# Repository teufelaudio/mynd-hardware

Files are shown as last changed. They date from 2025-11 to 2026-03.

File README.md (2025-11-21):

# Teufel MYND Hardware Repository
This repository contains all hardware related files including 3d models, schematics and pcb-layout files in various formats.

# Project structure
## `CAD/`
Contains 3d construction files in Rhino, STEP and STL formats. 
For every format, individual parts are available as direct download or a 'complete' package is avialable containing the entire model.
Due to size, the complete model in STL format is compressed into 'complete.zip'.

## `PCB_Schematics/`
### `./Altium`
Contains Altium Designer PCB and schematic files for all PCBs.
### `./KiCad`
Contains KiCad PCB and schematic files for all PCBs. Please note: These files were converted from the Altium working files for convenience and may still contain some  conversion errors.
### `./PDF`
Contains all schematic and assembly drawings exported to PDF from Altium files.

## Don't Yet Own a MYND Speaker!?
Purchase one [here](https://teufel.de/mynd)!

# Clone
```shell
git clone git@github.com:teufelaudio/mynd-hardware.git
```

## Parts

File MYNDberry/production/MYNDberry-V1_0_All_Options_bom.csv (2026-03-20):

Designator | Footprint | Quantity | Value | LCSC Part #
C1 | 0603 | 1 | 1µF/12V | C15849
C2 | 0603 | 1 | 2.2µF/16V | C23630
C3 | 0603 | 1 | 100nF/50V | C14663
CN1 | CONN-SMD_4P-P1.00_SHOU-HAN_1.0-4P-WT | 1 | 1.0-4P WT | C2906270
H1 | HDR-SMD_24P-P2.54-V-F-R2-C12-S7.4 | 1 | MYND_Main_PCB | C3294470
H2 | 2x40_2.54mm_Female_SMT_Vertical | 1 | RPi | C5345531
H3 | HDR-SMD_3P-P2.54-H-M_KH-2.54PH-1X3P-L13.5-WT | 1 | HX_PZ2.54-1X3P_WT | C46061676
Q1 | SOT-23-3_L2.9-W1.3-P1.90-LS2.4-BR | 1 | AO3400A | C20917
Q2 | SOT-23_L2.9-W1.3-P1.90-LS2.4-BR | 1 | AO3401A | C15127
R1, R3, R4, R5, R6, R7 | 0603 | 6 | 0R | C21189
R12, R9 | 0603 | 2 | 100k | C25803
R8 | 0603 | 1 | 470 | C23179
U1 | SOT-23-5_L3.0-W1.7-P0.95-LS2.8-BR | 1 | TPS70933DBVR | C89347
U2 | SOP-8_L4.9-W3.9-P1.27-LS6.0-BL | 1 | CH340N | C2977777

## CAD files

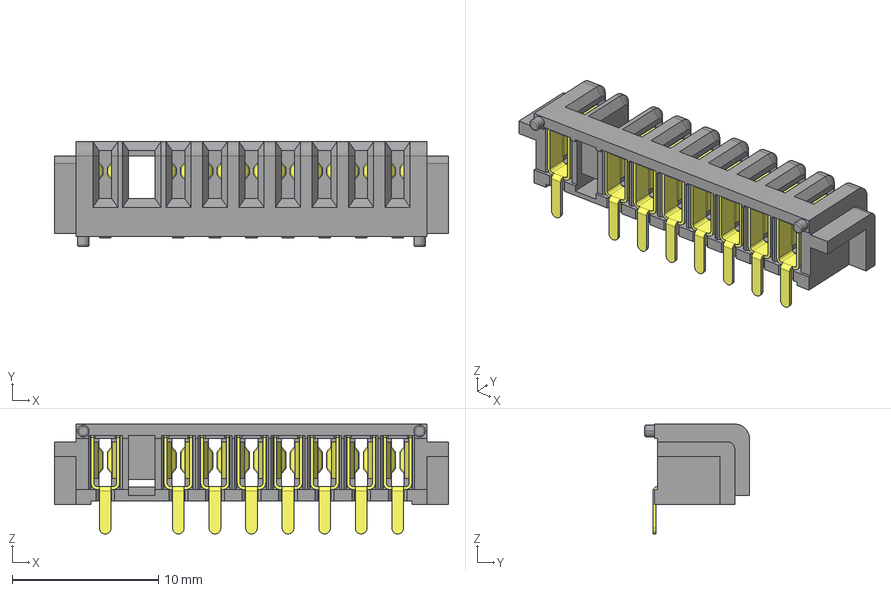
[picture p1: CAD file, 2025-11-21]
PCB_Schematics/KiCad/Conn_Amp/ALTIUM_EMBEDDED_MODELS/tsb0-0128d-00xxa_asm__sw0001.stp
26.9 x 7.18 x 7.52 mm

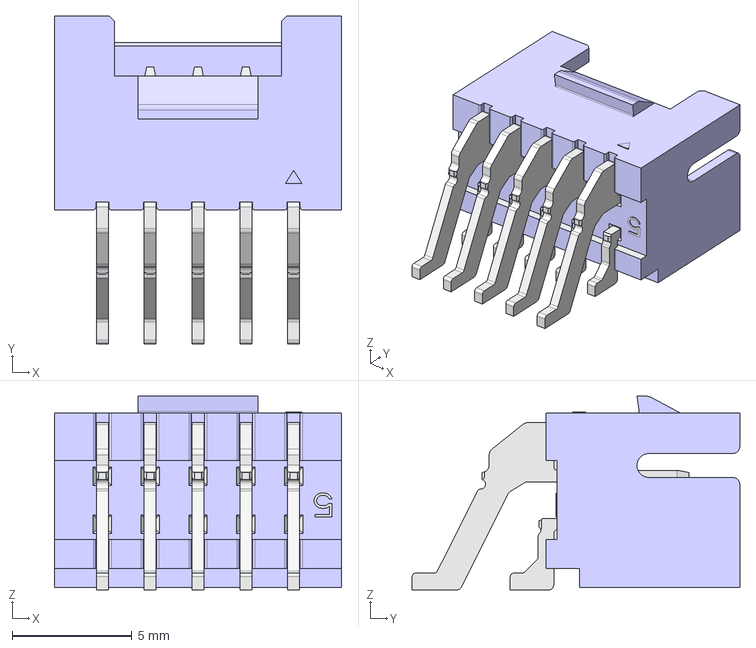
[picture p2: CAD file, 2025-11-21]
PCB_Schematics/KiCad/Jack_USB/ALTIUM_EMBEDDED_MODELS/PHB-ROW-ST-SMT-2-5P_ASM.step
12.0 x 13.7 x 8.10 mm

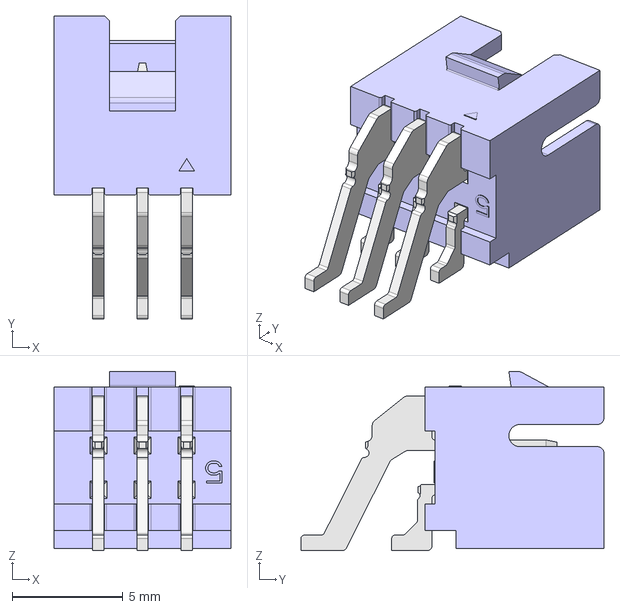
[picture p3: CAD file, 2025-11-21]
PCB_Schematics/KiCad/Jack_Line_In/ALTIUM_EMBEDDED_MODELS/phb-row-st-smt-2-3p_asm.stp
8.00 x 13.7 x 8.10 mm

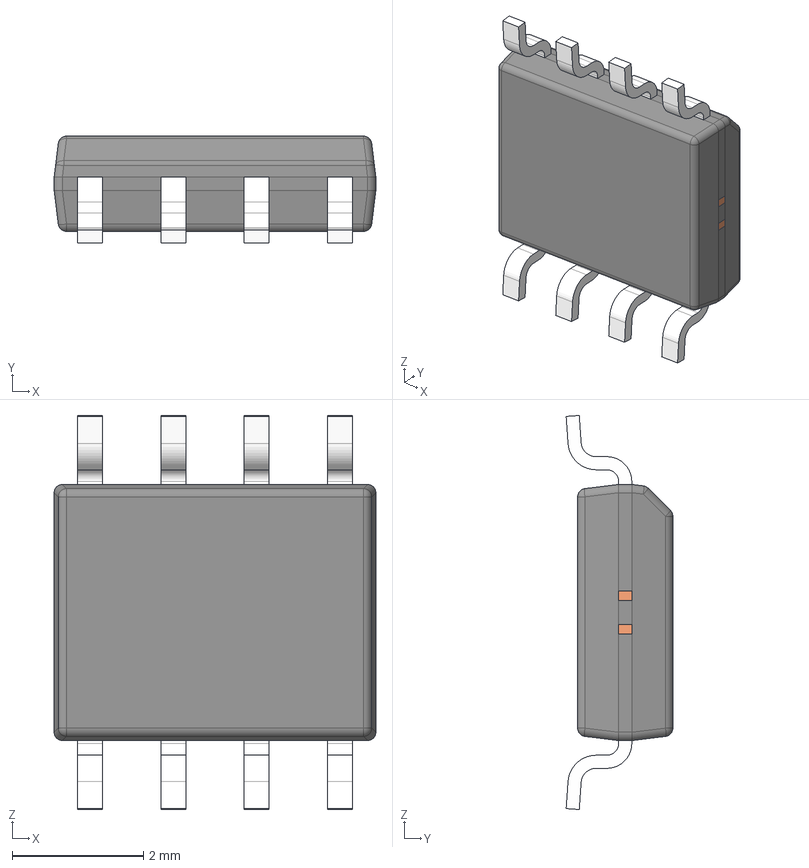
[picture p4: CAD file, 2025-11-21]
PCB_Schematics/Altium/Main/ALTIUM_EMBEDDED_MODELS/D0008A.stp
4.90 x 1.62 x 6.00 mm
BODY_M08A_35
LEAD_M08A_57 x 8
MANIFOLD_SOLID_BREP_2784
MANIFOLD_SOLID_BREP_2935
MANIFOLD_SOLID_BREP_3086
MANIFOLD_SOLID_BREP_3237

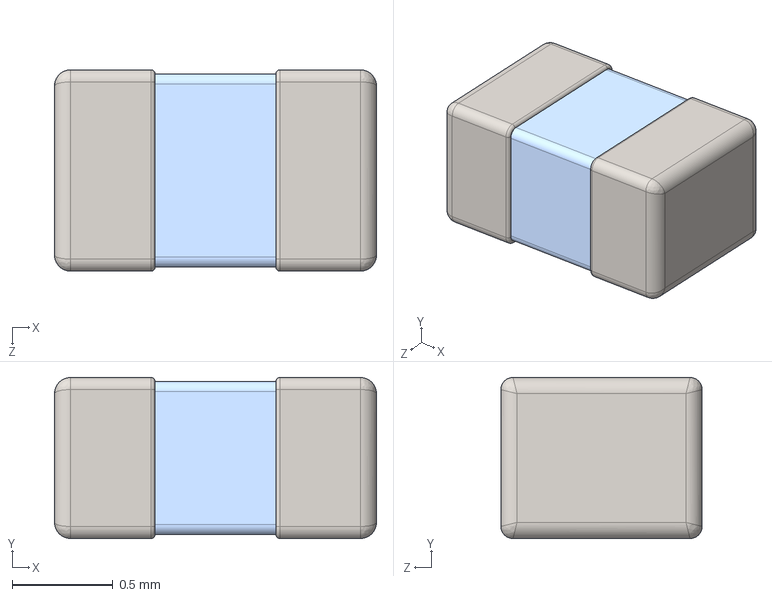
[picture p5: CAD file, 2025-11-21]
PCB_Schematics/KiCad/Amp/ALTIUM_EMBEDDED_MODELS/User Library-INDC1608X___.step
1.60 x 0.8 x 1.00 mm

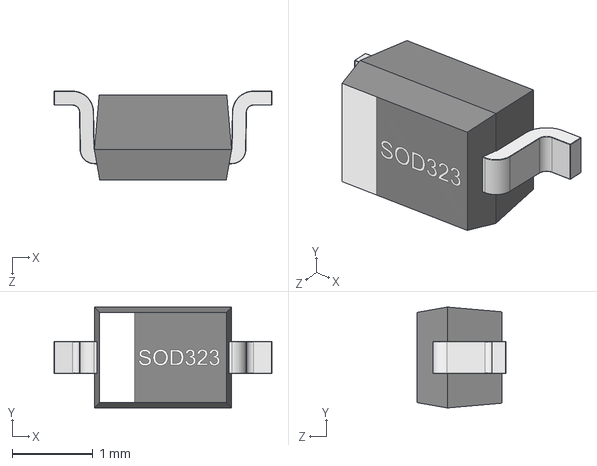
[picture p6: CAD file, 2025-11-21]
PCB_Schematics/KiCad/Bluetooth/ALTIUM_EMBEDDED_MODELS/User Library-SOD2513X11.STEP
2.70 x 1.25 x 1.10 mm

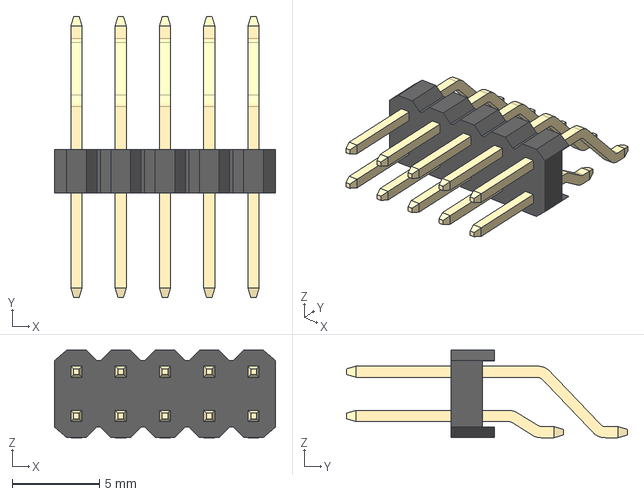
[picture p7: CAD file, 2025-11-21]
PCB_Schematics/KiCad/Conn_Amp/ALTIUM_EMBEDDED_MODELS/pin_header_a-sl254-da-g10mp1.stp
12.7 x 16.1 x 5.02 mm

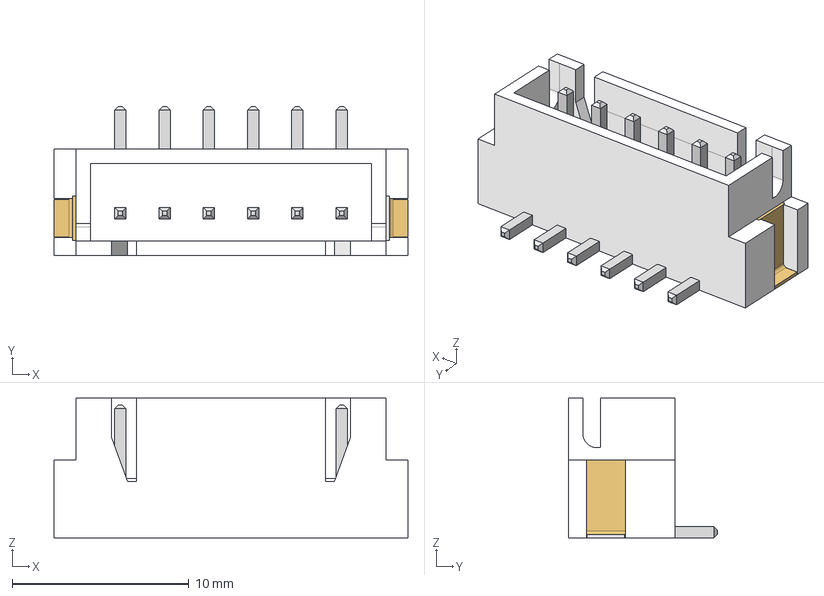
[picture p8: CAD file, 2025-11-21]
PCB_Schematics/KiCad/Conn_Baffle/ALTIUM_EMBEDDED_MODELS/A2501_6P.step
20.0 x 8.40 x 7.90 mm
Pin004
Pin005
Pin006
Pin007
Pin008
Pin009
FPin001
FPin002
FPin002_(Mirror_#1)

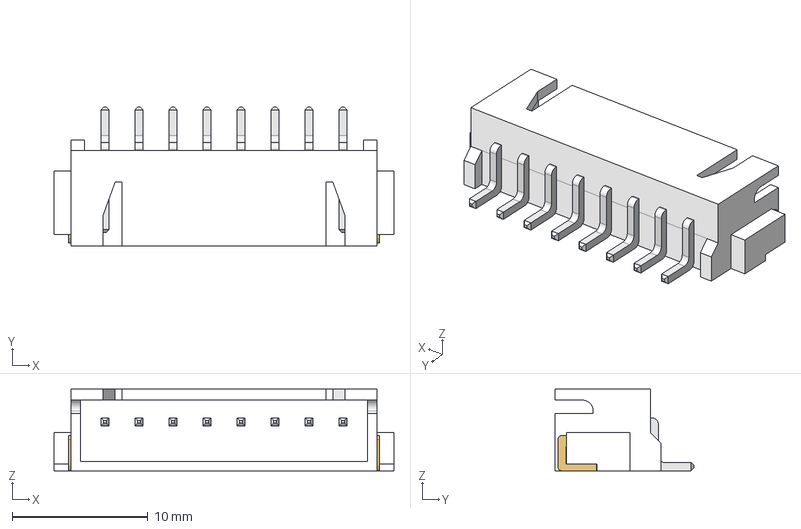
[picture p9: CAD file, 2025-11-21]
PCB_Schematics/KiCad/Conn_Bat/ALTIUM_EMBEDDED_MODELS/A2501W_8P.step
25.0 x 10.2 x 6.00 mm
FPin001
FPin002
FPin002_(Mirror_#1)
PIN001
PIN002
PIN003
PIN004
PIN005
PIN006
PIN007
PIN008

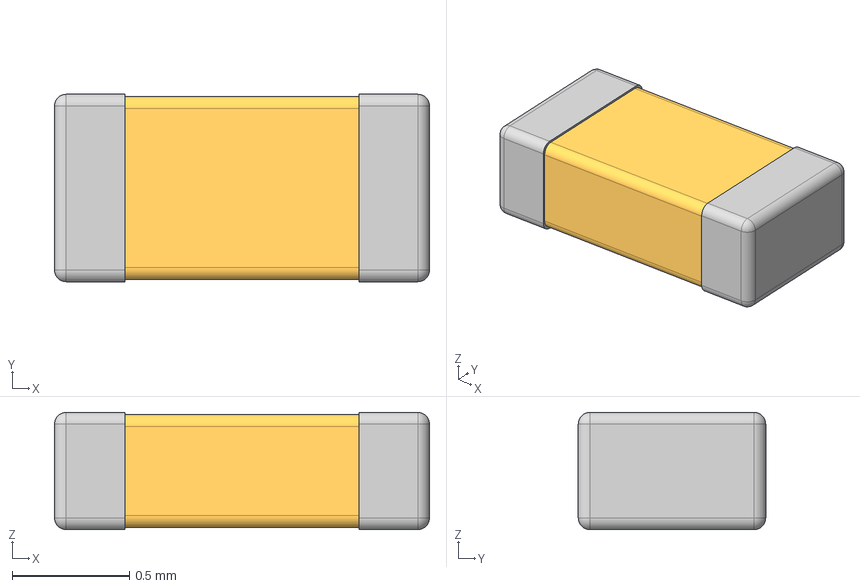
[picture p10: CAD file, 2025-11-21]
PCB_Schematics/KiCad/Jack_Line_In/ALTIUM_EMBEDDED_MODELS/0603_50.step
1.60 x 0.8 x 0.5 mm

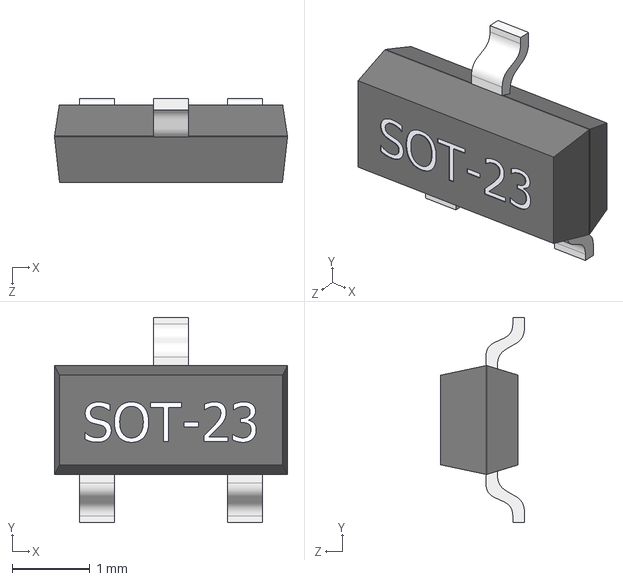
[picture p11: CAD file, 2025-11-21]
PCB_Schematics/KiCad/Main/ALTIUM_EMBEDDED_MODELS/User Library-SOT-23-2.STEP
3.00 x 2.64 x 1.08 mm

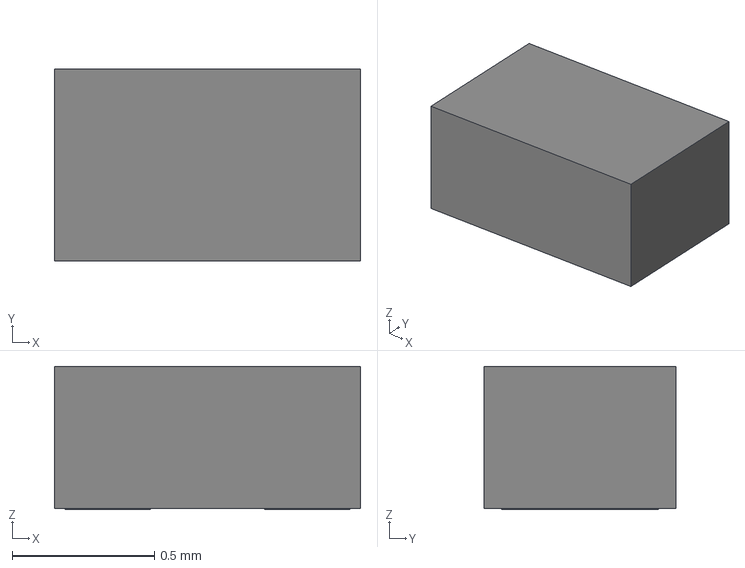
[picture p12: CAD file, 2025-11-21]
PCB_Schematics/KiCad/UI/ALTIUM_EMBEDDED_MODELS/DFN70P101X50-2N.step
1.07 x 0.675 x 0.503 mm
bigPin x 2

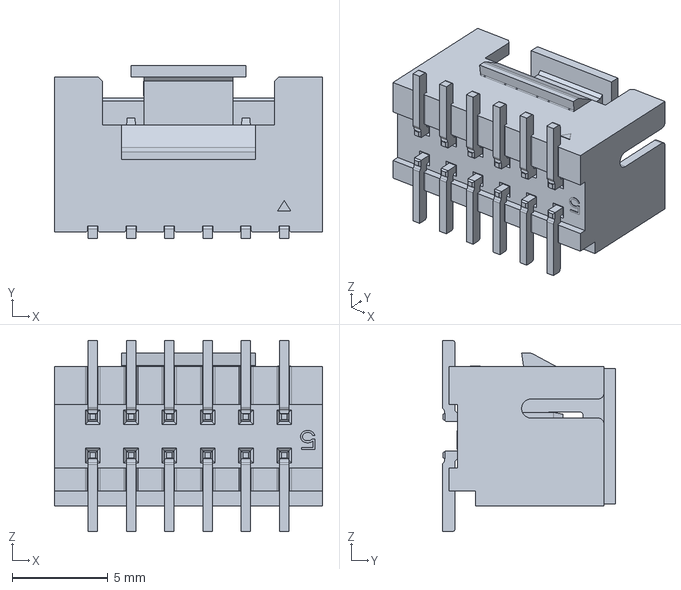
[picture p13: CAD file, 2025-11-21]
PCB_Schematics/Altium/Main/ALTIUM_EMBEDDED_MODELS/WB200AL-12.stp
14.0 x 9.03 x 10.0 mm

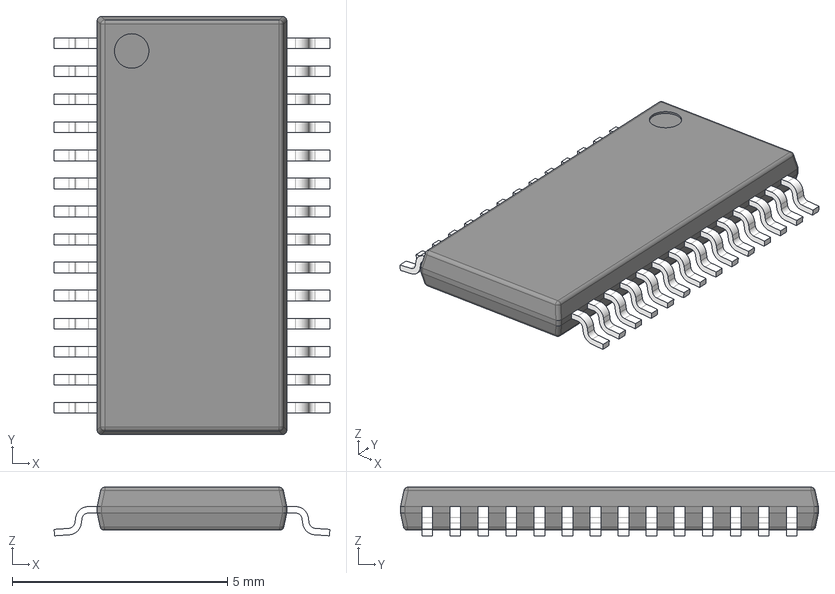
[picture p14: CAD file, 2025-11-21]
PCB_Schematics/KiCad/Amp/ALTIUM_EMBEDDED_MODELS/PWP0028C.stp
6.40 x 9.70 x 1.13 mm
BODY-TSSOP
LEAD-TSSOP x 28
PIN1
DAP

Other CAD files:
PCB_Schematics/KiCad/Jack_USB/ALTIUM_EMBEDDED_MODELS/SCM7060.step
PCB_Schematics/Altium/Main/ALTIUM_EMBEDDED_MODELS/0603_105.step
PCB_Schematics/Altium/Main/ALTIUM_EMBEDDED_MODELS/0603_80.step
PCB_Schematics/Altium/Main/ALTIUM_EMBEDDED_MODELS/0805_145.step
PCB_Schematics/Altium/Main/ALTIUM_EMBEDDED_MODELS/20-wtb-a-double-row-st-smt-2x5p(1).stp
PCB_Schematics/Altium/Main/ALTIUM_EMBEDDED_MODELS/6.3x5.4_Chip.stp
PCB_Schematics/Altium/Main/ALTIUM_EMBEDDED_MODELS/610024243021 (rev1).stp
PCB_Schematics/Altium/Main/ALTIUM_EMBEDDED_MODELS/744231061_Download_STP_WE-CNSW-0805_rev1.stp
PCB_Schematics/Altium/Main/ALTIUM_EMBEDDED_MODELS/8x10_Chip.stp
PCB_Schematics/Altium/Main/ALTIUM_EMBEDDED_MODELS/DBV0003A.stp
PCB_Schematics/Altium/Main/ALTIUM_EMBEDDED_MODELS/DGK0008A.stp
PCB_Schematics/Altium/Main/ALTIUM_EMBEDDED_MODELS/DQH0008A.stp
PCB_Schematics/Altium/Main/ALTIUM_EMBEDDED_MODELS/JSHC0630.step
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

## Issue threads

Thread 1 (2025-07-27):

Extension Boards - Getting Started

gramss, 2025-07-27:
Hallo,

Ich habe großes Interesse an der Box und die Möglichkeiten sie selbst erweitern zu können.
Gibt es Hinweise / Beschreibungen zur Integration von möglicher Zusatzhardware?

Bisher habe ich nur den drei poligen UART PIN ausfindig machen können.

Wäre über Hinweise und mögliche existierenden oder sogar Beispiel Projekte (LED blinken lassen via Knopf und/oder Sound via SPI übertragen) sehr dankbar.. ☺️

Grüßla

markus-seidl, 2025-09-24:
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

Postponing my purchase until this is release, as I want to use the MYND as juke box for my kid and that ability would be mandatory for it.

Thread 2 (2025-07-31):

Better Audio Codecs possible? e.g. by Exchanging ATS2835P for ATS2835P2?

btittelbach, 2025-07-31:
# Problem

currently the MYND only supports the SBC Bluetooth audio codec which is rather low quality.

Many codecs (basically anything else is better than SBC) with better audio quality exist and we would like to find a way to use at least one that is better than SBC.

# Context Information

## The IC on which everything depends

- the MYND uses the ATS2835P for all things pre-amp audio including bluetooth
- the ATS2835P includes a very very powerful DSP that should be able to handle all kinds of codecs without problem
- the datasheet of ATS2835P says it integrates AAC but not LE-audio and party-link broadcasts only via Broadcom CSB
- the ATS2835P2 would support Auracast broadcast to all standard-conforming bluetooth speakers and LE-Audio

## Bluetooth Audio Codecs

- SBC: the very very old, very basic, somewhat power hungry, not very good sounding first bluetooth audio codec. It's only advantage is that it often works no matter how packed the 2.4ghz spectrum is.
- SBC-XQ: an easy hack to make SBC a lot better, only available on linux and android custom roms. The MYND accepts SBC-XQ streams but stays silent, unfortunately. Also needs more bandwidth.
- AAC: very very bad on anything other than iPhones, even on Macs. On iPhones however, as good as LDAC. Unknown licensing situation.
- APT-X HD: a very good audio codec that uses lot's of bandwith (but who cares if you're outside or on a Festival where there is no interference) Uses slightly more battery.
- APT-X Adaptive: a very very good audio codec that balances bandwidth and audio quality on demand.
- LDAC: The best bluetooth audio codec. Can also balance bandwidth and audio quality on demand. Uses slightly more battery. Needs licensing.
- LDHC: never seen it in real life. supposedly as good as LDAC
- LC3plus: supposedly very good, never seen in real life or on any datasheet.
- opus: very very good audio quality, bandwith-saving, royality free codec. Supposedly supported by ATS2835P. Supported by all newer Android, Linux, Windows.

# Possible Solutions

## opus

The ATS2835P should be able to handle opus without sweat.

Information on how to enable it or add it to the ATS2835P firmware remain opaque.

This would be the best solution. Opus is bandwith saving, high audio quality, widely supported and royalty free.

Question @toxxin : how does Teufel choose the features backed into the ATS2835P? Do you just check a bunch of boxes when ordering the module?

## aac

the datasheet says that ATS2835P says that AAC is supported out of the box. Since we know from tests that the MYND does not actually support AAC, it must have been disable on purpose.

Enabling it would at least help iPhone users, if more than useless for everybody else.

## LDAC

If I could somehow get the option, to personally pay the licensing cost for LDAC and enable it on my MYND, I would do it in hearbeat.

## Using the ATS2835P2

that one supposedly supports LE-Audio which should include the LC3 Codec.
If so...  That would just sufficiently improve audio quality, while also reducing bandwith usage, battery power and enable broadcast compatibility with all standard conforming devices.

Question @toxxin Would be ATS2835P2 be a drop-in replacement?
How could be go about obtaining that chip and module?
Would we also have to obtain it'sfirmware?

jonamb, 2025-08-11:
Hi @btittelbach,
thanks for your detailed description! I'll try to respond as much as I can.

About the choice of codecs, this is based on lots of factors including availability of codecs on the BT module/IC itself, certification effort, licencing cost for different codecs, weighing the advantages for users versus the increased final product price etc.

I'll bring up the idea allowing individual users to pay for codecs "à la carte" in the next meetings, this could be a nice compromise between cost and features!

About the ATS2835P2, this ic would solve a lot of problems but sadly isn't market ready yet. We are evaluating releasing a conversion kit once it is ready for release. Since the ic uses a newer version of the sdk and includes new features such as auracast, the firmware on both ends will have to be updated as well so it would probably not be immediately after launch.

tg--, 2025-10-06:
I have another device using a "Actions" BT SoC, a Beyerdynamic MMX200. Here the AT2831P is used instead of the AT2835P, but its a very similar SoC with basically the same specs and a slightly older bluetooth IP core.

It too, does not support SBC-XQ, while it clearly has more than enough hardware and radio capacity to do so, which leads me to believe the issue is just a poor implementation of the BT spec. They likely only target the "default" parameters and don't accept the ones the specification mandates.

All other BT audio receivers I have do accept SBC-XQ without issues, just the Actions ones do not.

Just to make it clear, in case not everyone knows: SBC-XQ is no independent codec, it is just a set of specific parameters for the bluetooth-default codec SBC, which pushes the bitrate to the upper end of the specification, while not exceeding it.
This works for all devices implementing BT according to the spec (even very old ones!), but may fail if devices only support the most common parameters, as used by default on Android and a few vendor stacks.

Maybe Teufel could fix that with access to the Actions SDK, these are probably parameters that could be set:
- SBC Dual Channel as alternative to Joint-Stereo support (this is the magic that doubles the bitrate)
- Number of SBC Subbands: 8
- Bitpool 38 (or 47 for even higher bitrates, possible with BT EDR3)
- Block Length: 16

In my tests, I can't distinguish SBC-XQ from the expensive high-end codecs like aptX-HD and LDAC, it seems transparent to me (and most others who tested it), so it would be a great - free - upgrade, of sound quality.
This is in stark contrast to e.g. AAC as implemented in Android, which usually is very poor in quality (in my case generally outperformed by standard-SBC), which is a widely known issue. AAC on Apple devices is supposed to be fine (can't test it).

Now for the bad news: even though patches for SBC-XQ support have been submitted to google since 2019, they will not take them and likely never support it.
LineageOS did have support for years, but it got dropped, since they went back to upstream AOSP parameters.
Apple will likely never support it.

This leaves MS Windows, which does not support SBC-XQ out-of-the-box, but via a 3rd party driver.
And Linux which does support it in basically all variants (ALSA, pulseaudio, pipewire).

TLDR; SBC-XQ is an immense upgrade and it would be totally free (no new hardware, no licensing, no patent issues), but basically only Linux users can take advantage of it.

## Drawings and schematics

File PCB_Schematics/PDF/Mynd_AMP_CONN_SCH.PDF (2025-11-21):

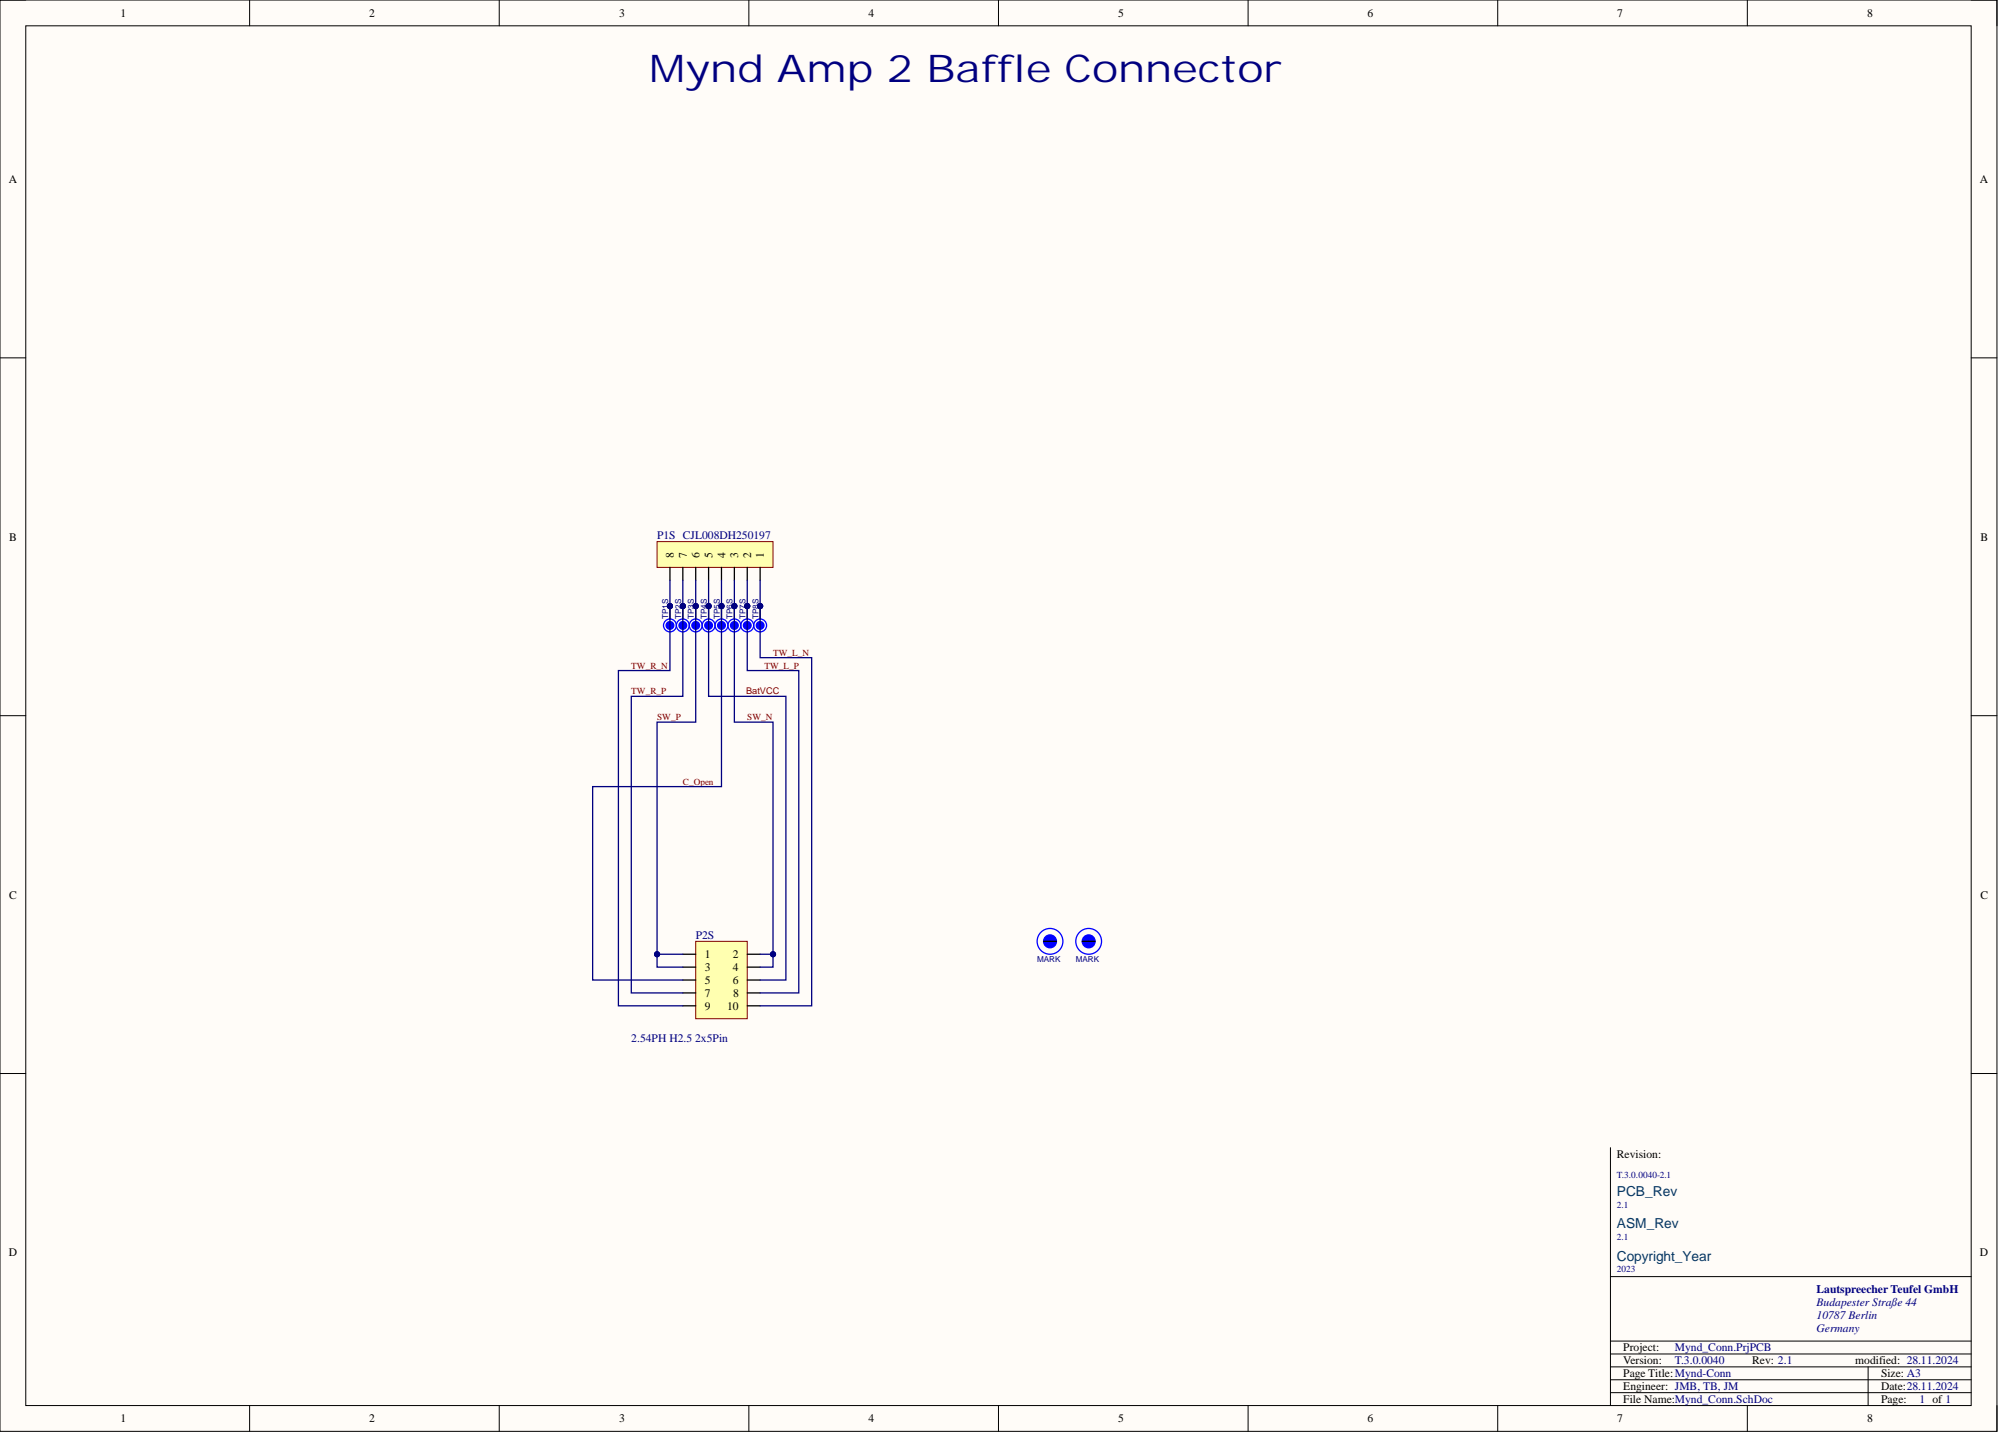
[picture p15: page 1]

Mynd Amp 2 Baffle Connector

TW_R_P | | BatVCC

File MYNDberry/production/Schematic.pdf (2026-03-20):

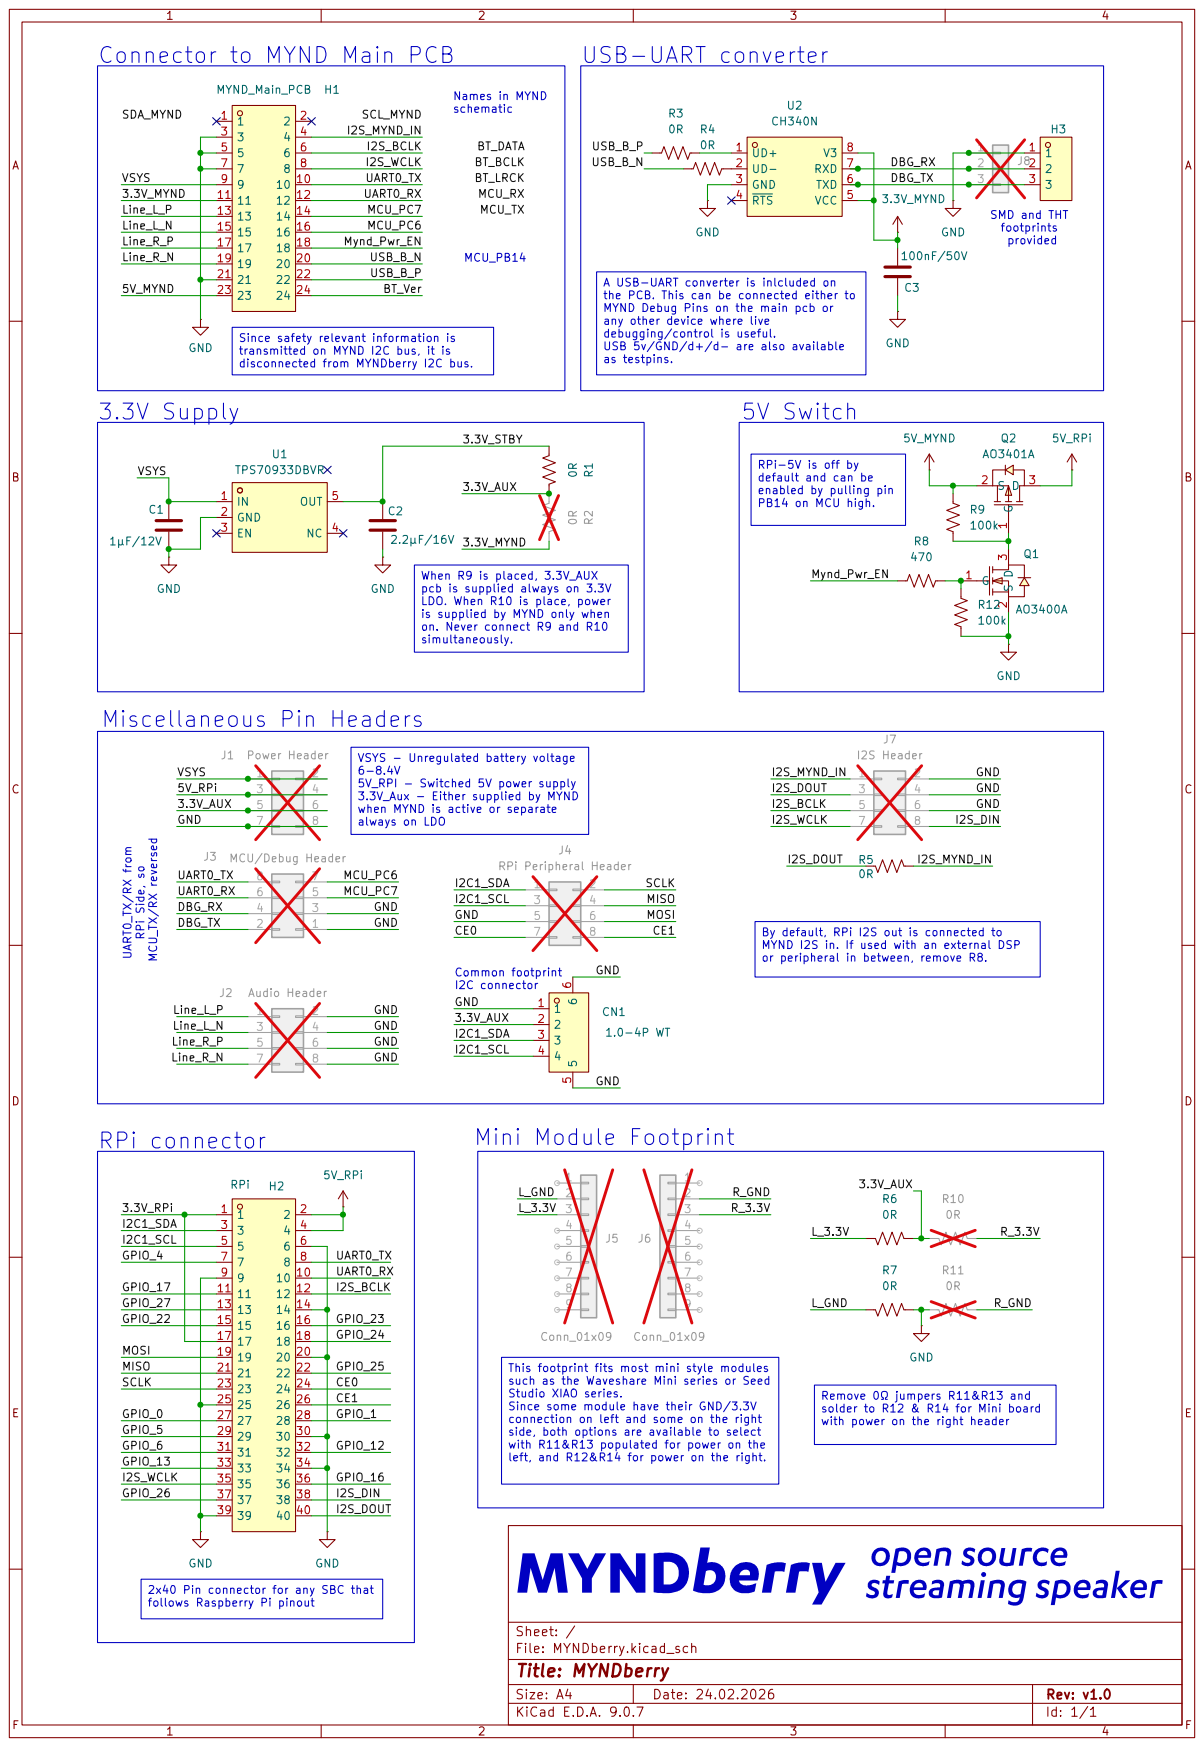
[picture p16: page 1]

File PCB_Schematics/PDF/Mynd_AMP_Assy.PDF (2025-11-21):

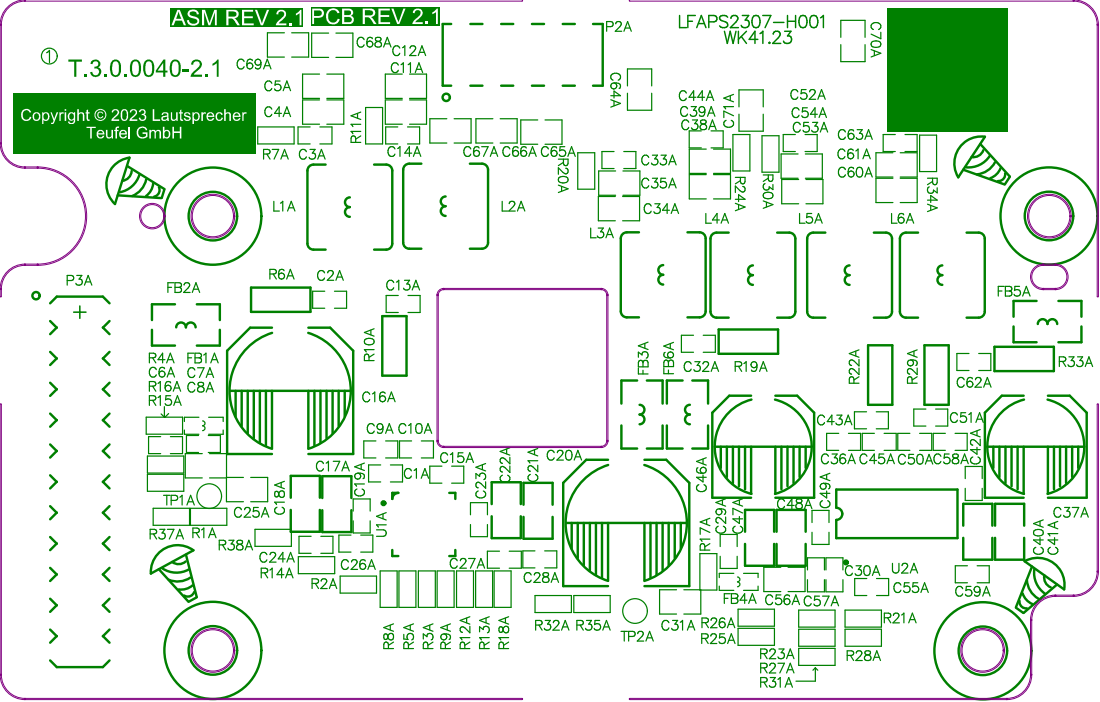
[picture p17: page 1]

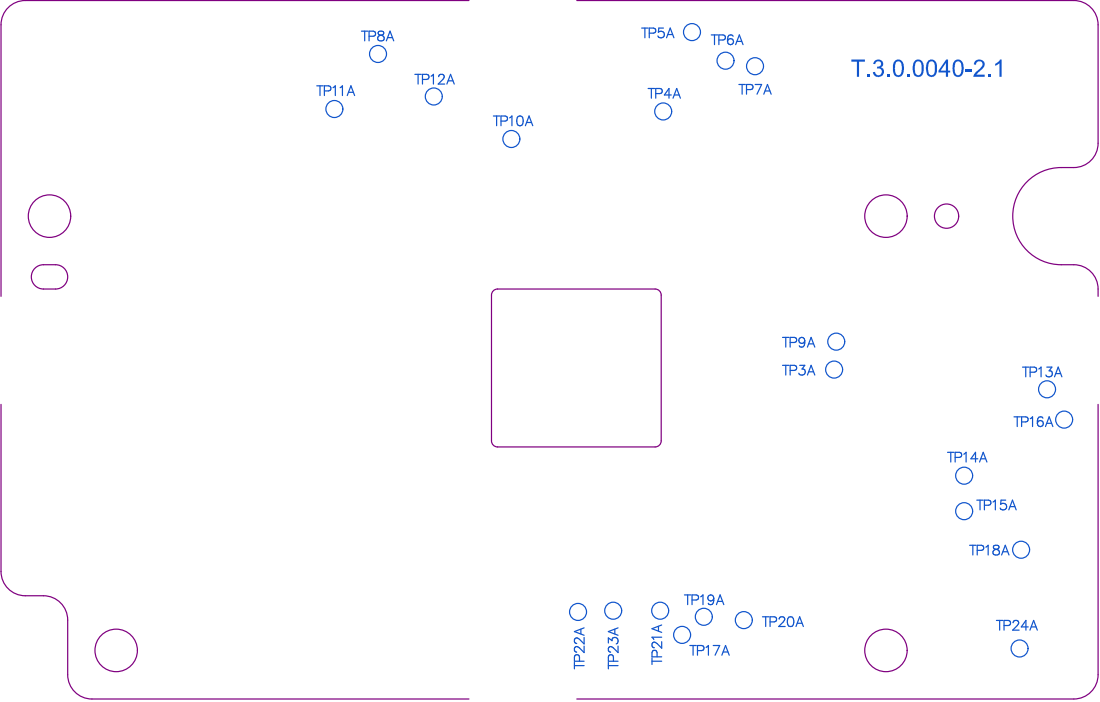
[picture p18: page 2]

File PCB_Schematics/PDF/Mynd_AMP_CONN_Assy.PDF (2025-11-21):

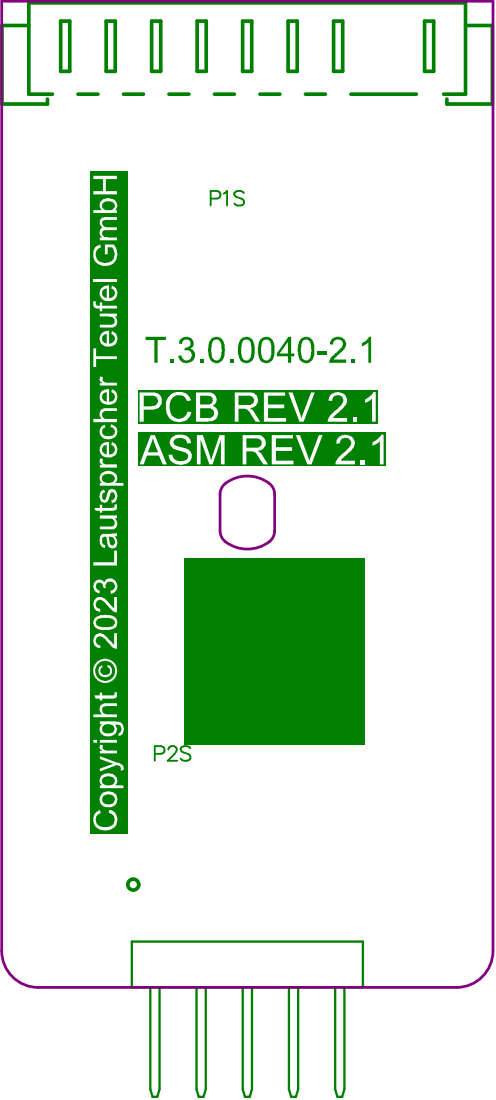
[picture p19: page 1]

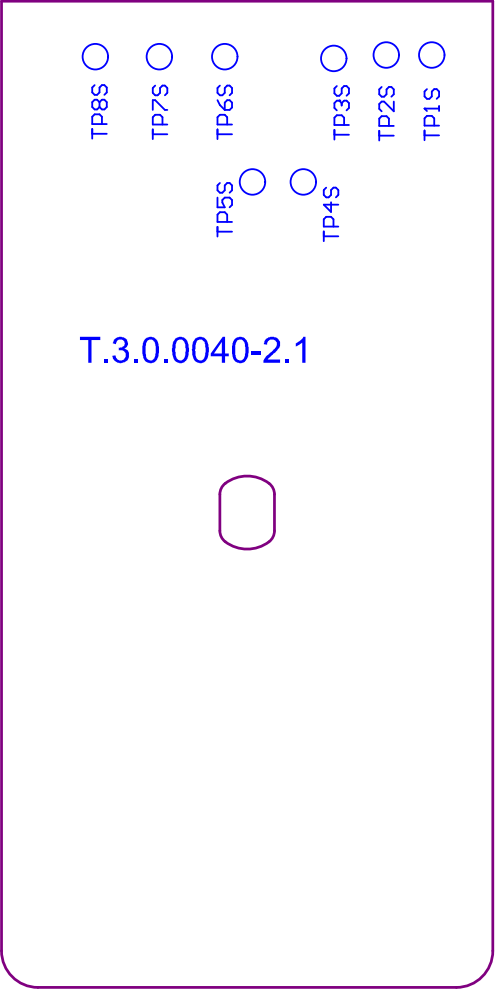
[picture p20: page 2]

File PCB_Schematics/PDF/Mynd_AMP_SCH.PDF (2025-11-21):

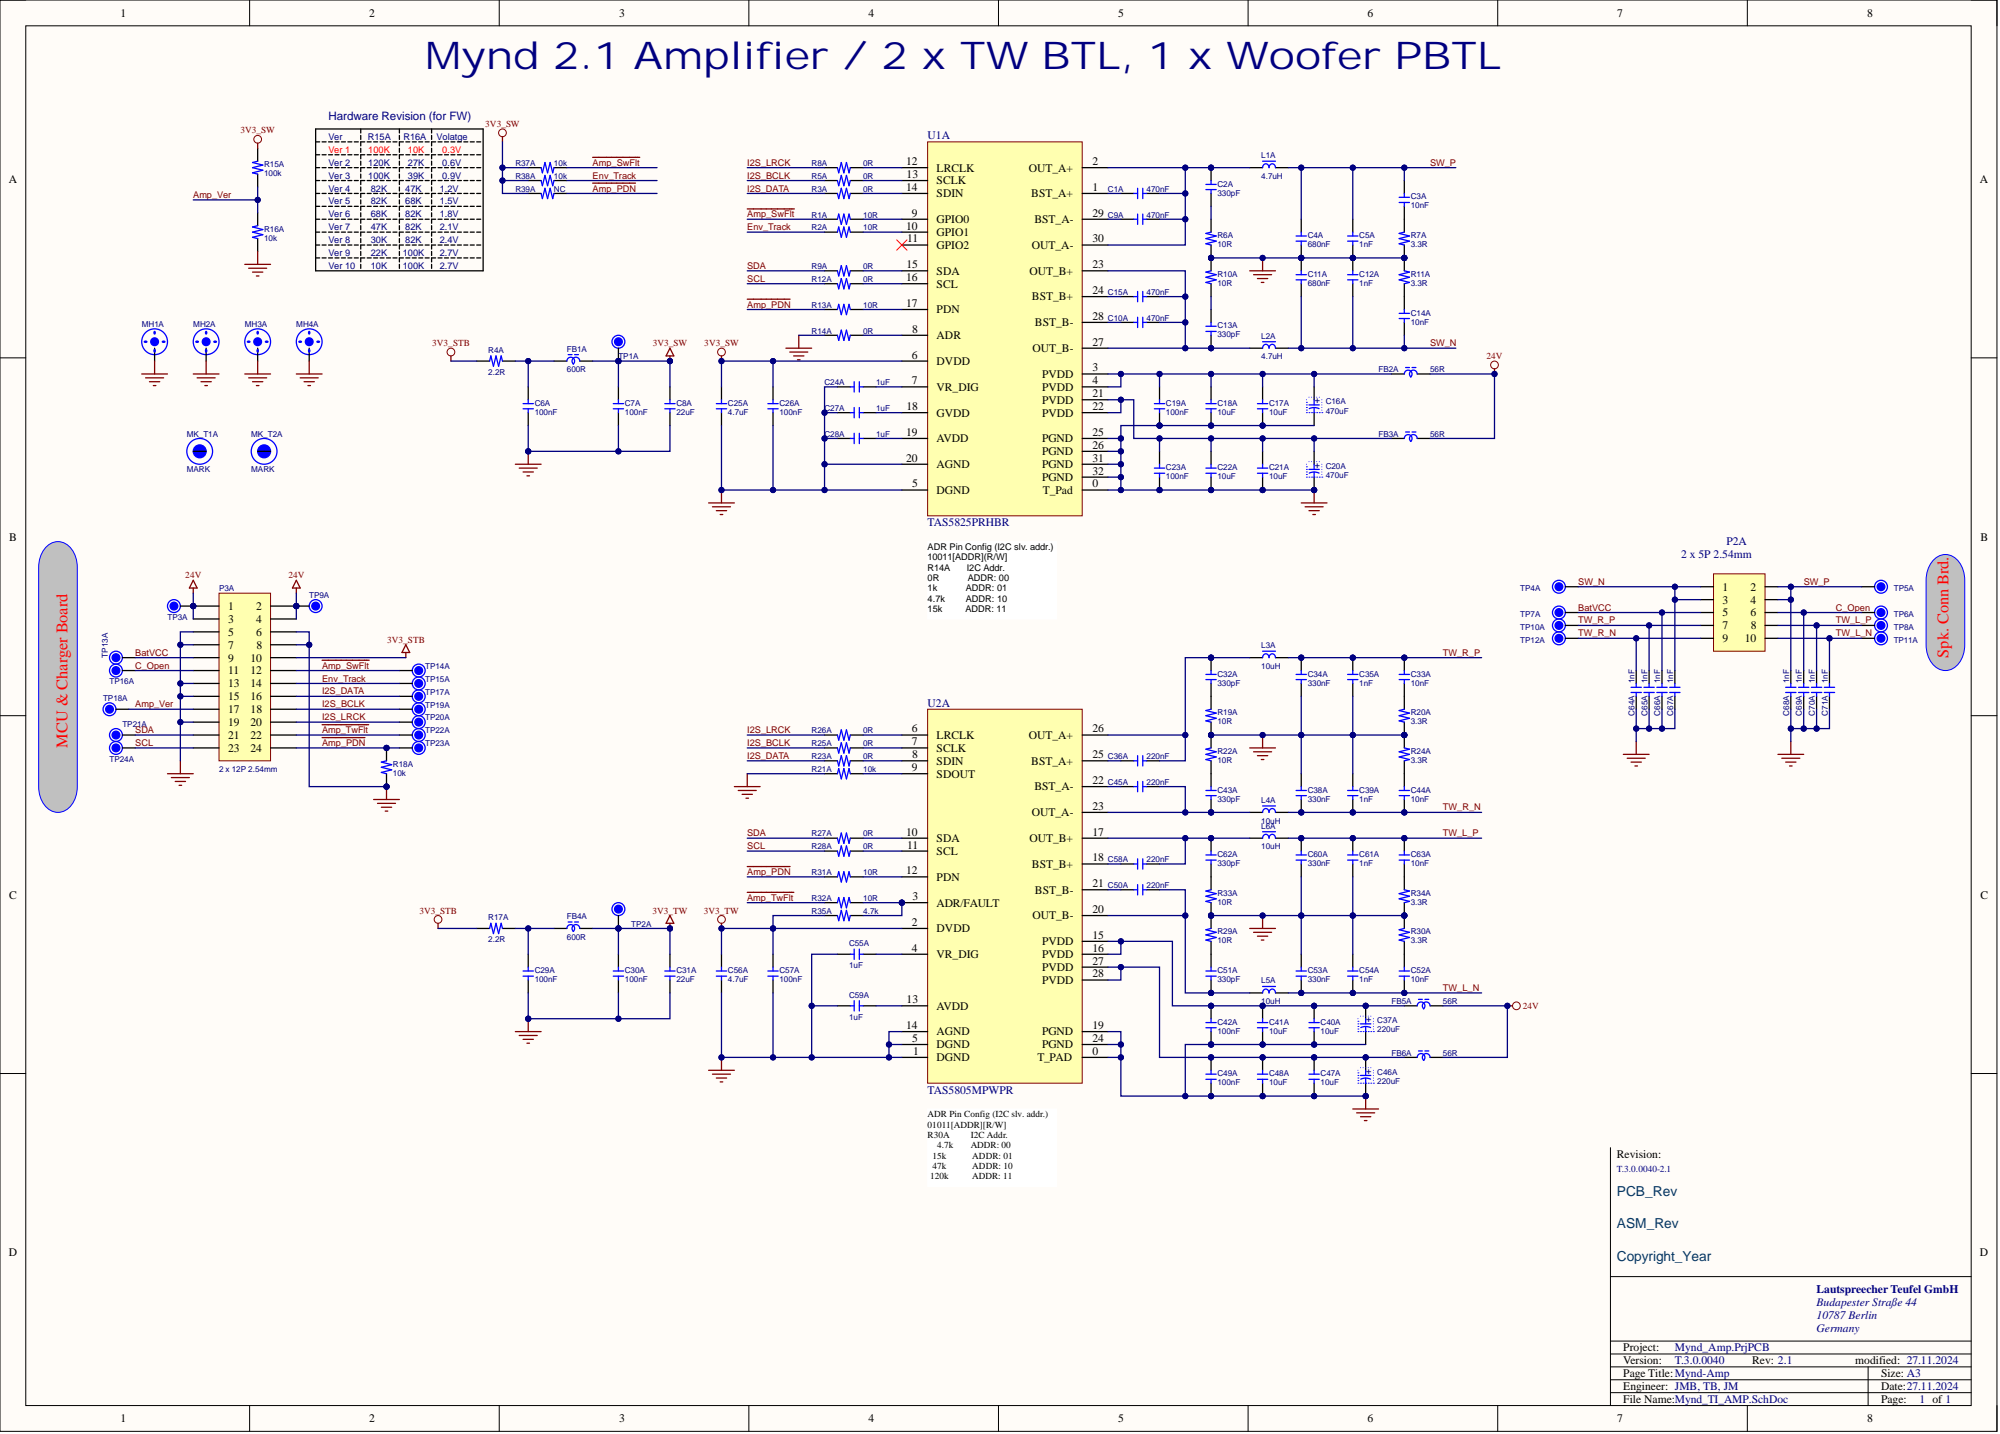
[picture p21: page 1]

Mynd 2.1 Amplifier / 2 x TW BTL, 1 x Woofer PBTL

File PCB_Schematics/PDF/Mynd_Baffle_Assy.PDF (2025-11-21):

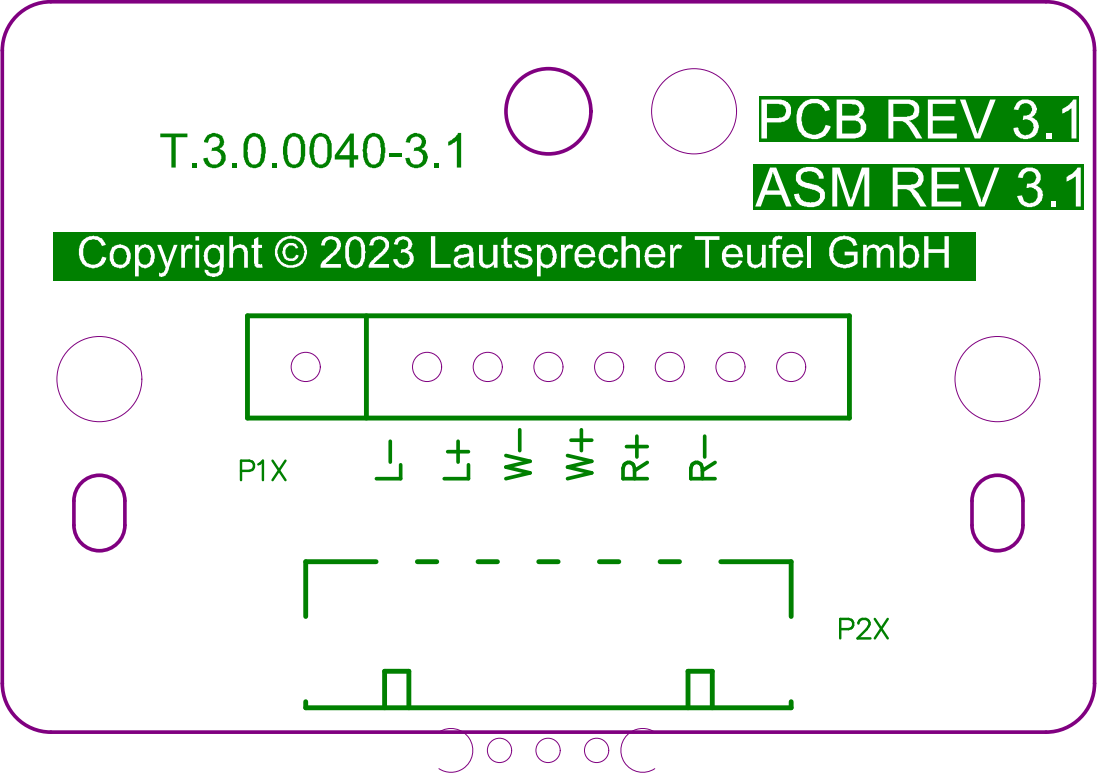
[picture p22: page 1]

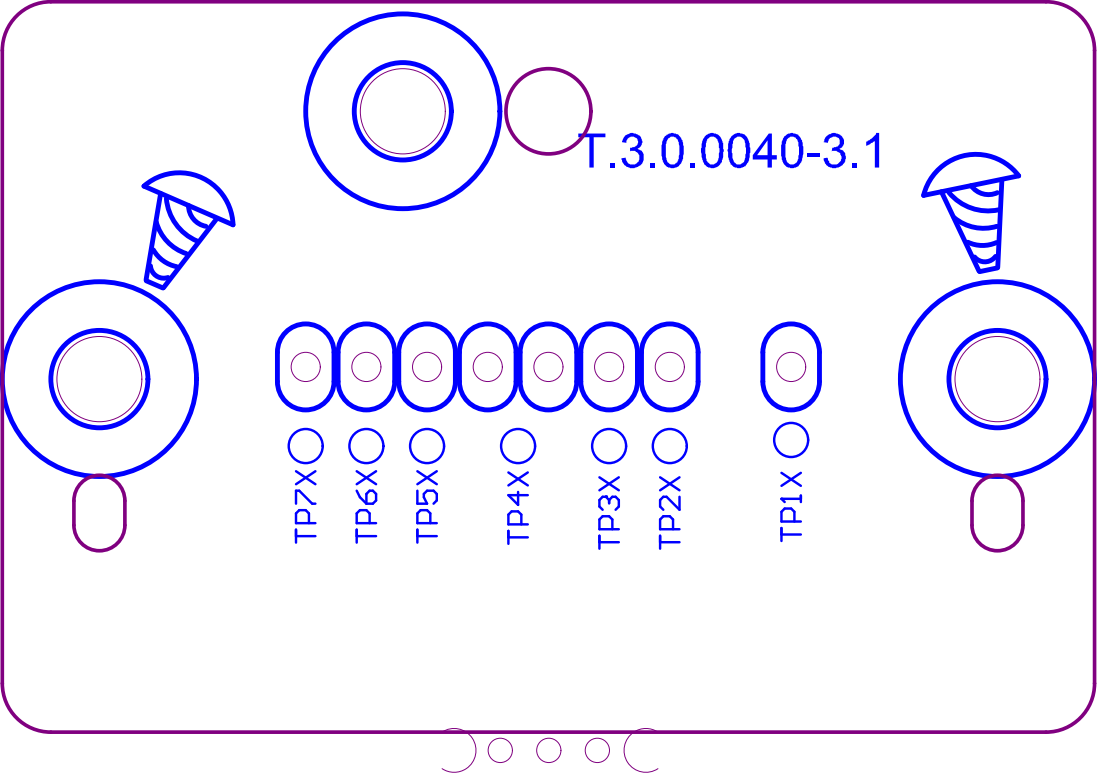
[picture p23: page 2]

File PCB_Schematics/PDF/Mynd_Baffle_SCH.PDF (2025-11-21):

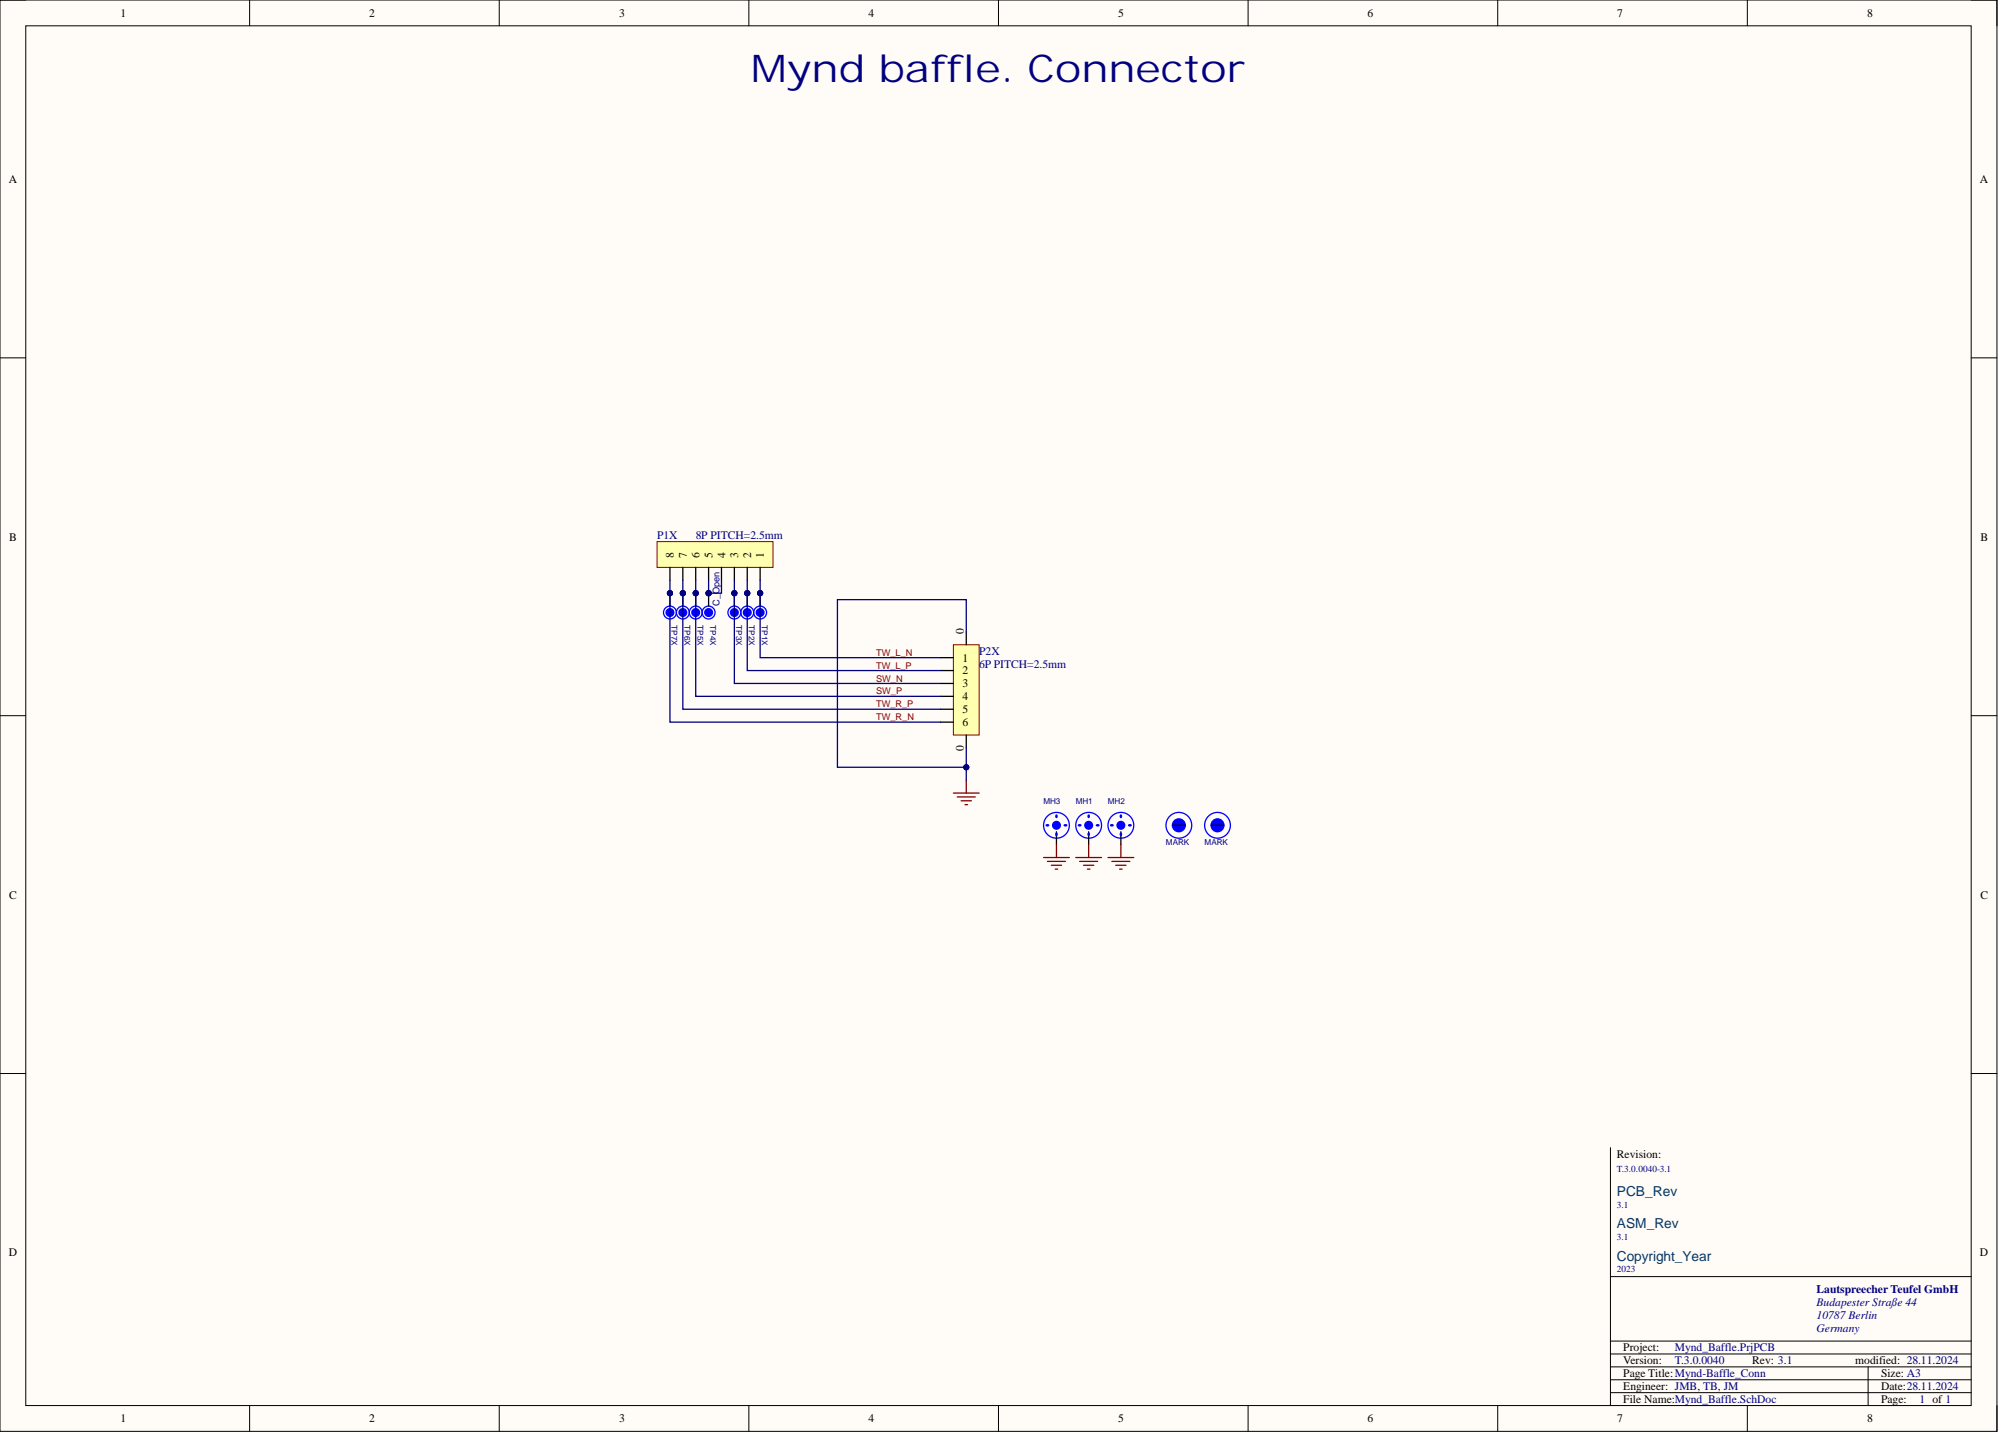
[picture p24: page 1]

TW_L_N
TW_L_P
SW_N
SW_P
TW_R_P
TW_R_N

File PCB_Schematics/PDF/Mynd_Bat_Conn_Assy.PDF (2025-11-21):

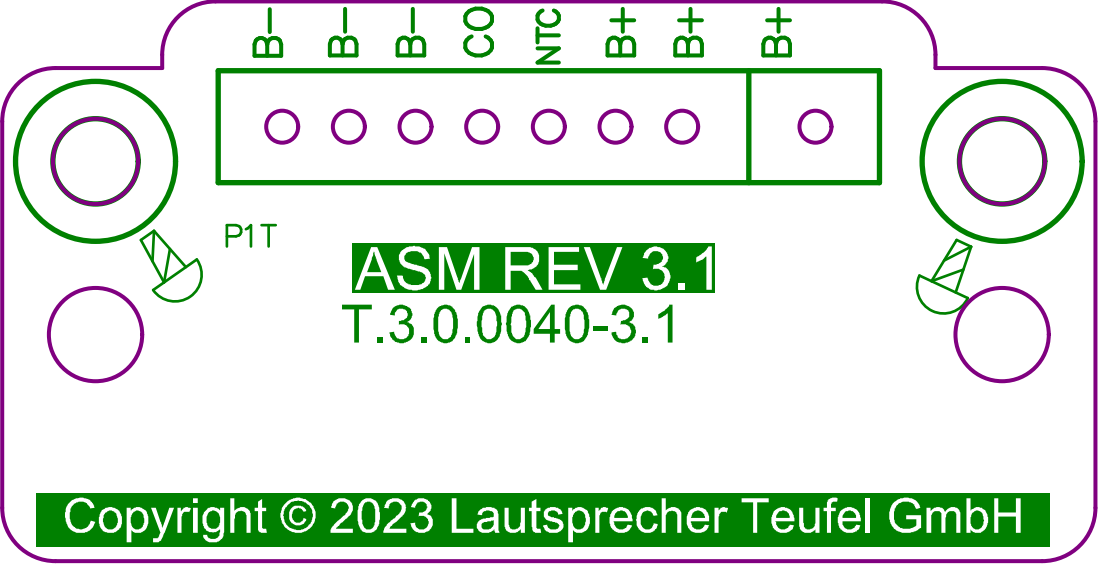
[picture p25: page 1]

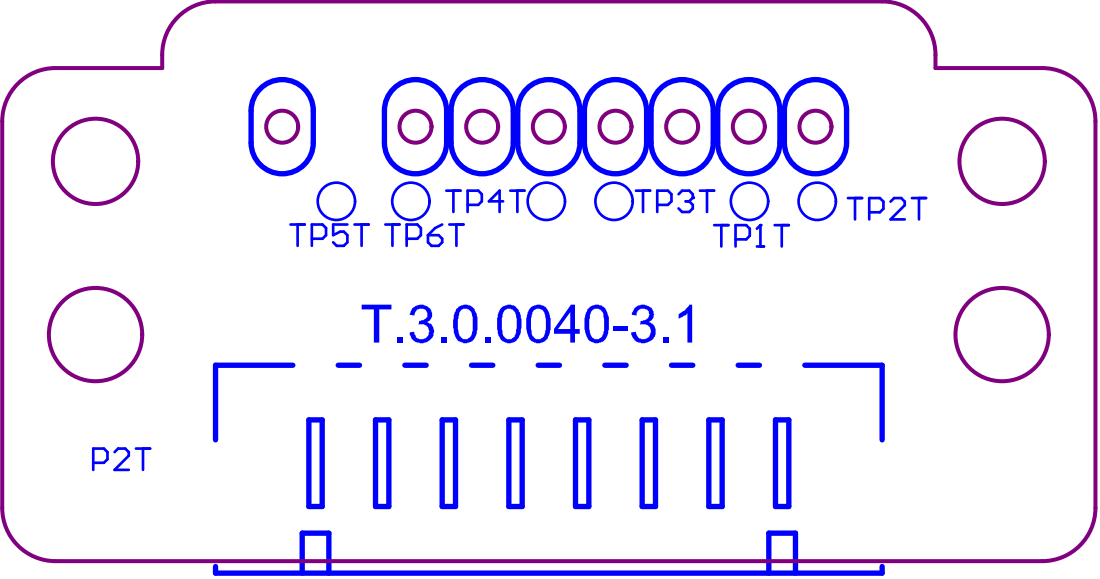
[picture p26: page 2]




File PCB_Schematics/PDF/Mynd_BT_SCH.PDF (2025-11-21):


Mynd Bluetooth & Line In

6 PSRAM_SC L K

SI/SIO[0] SO/SIO[1]

5 PSRAM_SIO 0
2 PSRAM_SIO 1
3 PSRAM_SIO 2 | | R31
7 PSRAM_SIO 3 | R32

3 | SO SI | 6 HOLD# 2 WP# FLASH_SCL K R35

8 | VCC VSS | FLASH_MIS O R36

R18 W 33k | C32
C33



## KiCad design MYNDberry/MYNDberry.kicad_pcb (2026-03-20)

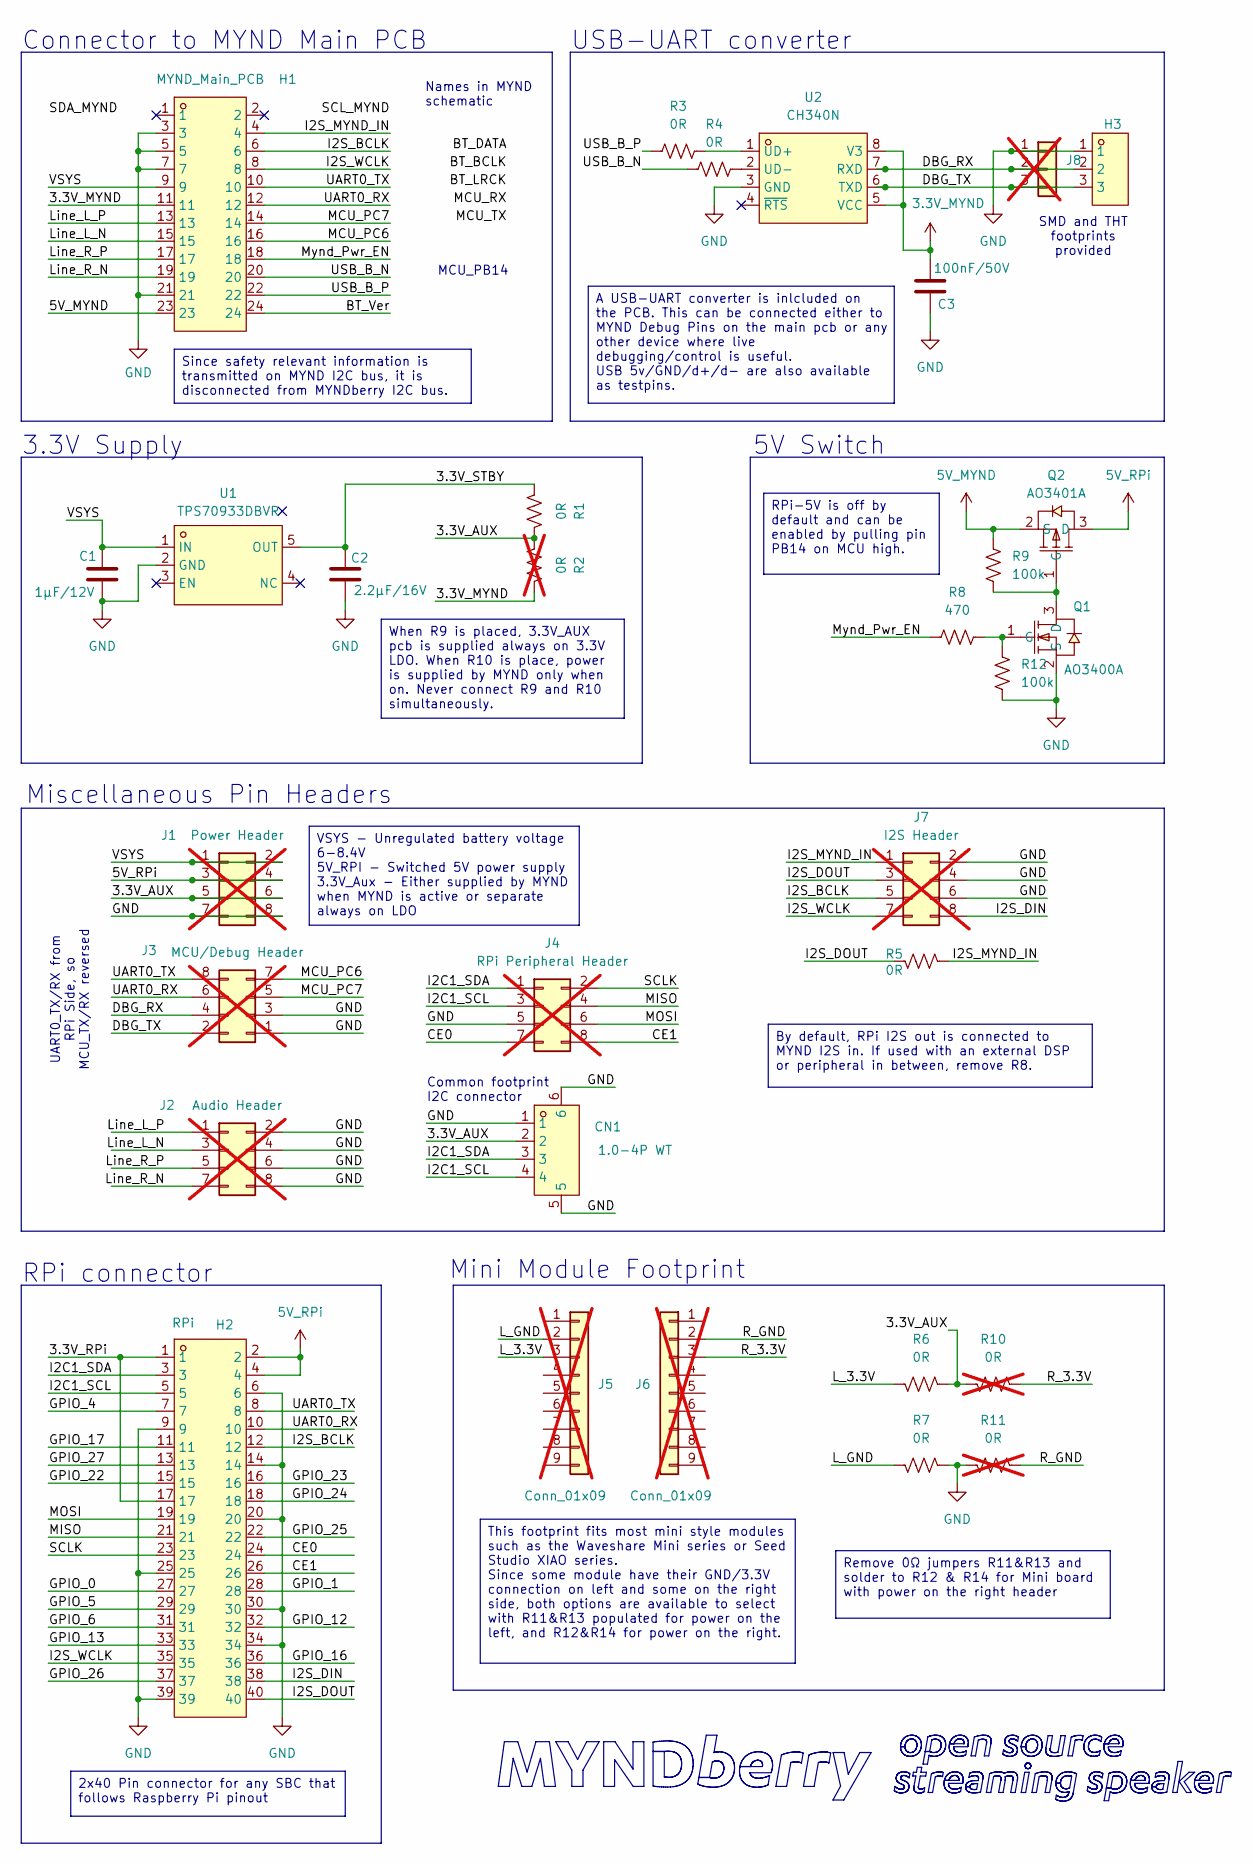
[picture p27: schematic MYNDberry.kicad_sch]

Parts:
C1: 1µF/12V; C_0603_1608Metric; LCSC C15008
C2: 2.2µF/16V; C_0603_1608Metric; LCSC C15008
C3: 100nF/50V; C_0603_1608Metric; LCSC C15008
CN1: 1.0-4P WT; CONN-SMD_4P-P1.00_SHOU-HAN_1.0-4P-WT; LCSC Part C2906270
H1: MYND_Main_PCB; HDR-SMD_24P-P2.54-V-F-R2-C12-S7.4; LCSC Part C3294470
H2: RPi; 2x40_2.54mm_Female_SMT_Vertical; LCSC Part C5345531
H3: HX_PZ2.54-1X3P_WT; HDR-SMD_3P-P2.54-H-M_KH-2.54PH-1X3P-L13.5-WT; LCSC Part C46061676
J1: Power Header; PinHeader_2x04_P2.54mm_Small_Outline; not fitted
J2: Audio Header; PinHeader_2x04_P2.54mm_Small_Outline; not fitted
J3: MCU/Debug Header; PinHeader_2x04_P2.54mm_Small_Outline; not fitted
J4: RPi Peripheral Header; PinHeader_2x04_P2.54mm_Small_Outline; not fitted
J5: Conn_01x09; 9P_SolderPad_TH_Left; not fitted
J6: Conn_01x09; 9P_SolderPad_TH_Right; not fitted
J7: I2S Header; PinHeader_2x04_P2.54mm_Small_Outline; not fitted
J8: Conn_01x03; PinHeader_1x03_P2.54mm_Vertical; not fitted
Q1: AO3400A; SOT-23-3_L2.9-W1.3-P1.90-LS2.4-BR; LCSC Part C20917
Q2: AO3401A; SOT-23_L2.9-W1.3-P1.90-LS2.4-BR; LCSC Part C15127
R1, R3, R4, R5, R6, R7: 0R; R_0603_1608Metric; LCSC Part C21189
R2, R10, R11: 0R; R_0603_1608Metric; not fitted
R8: 470; R_0603_1608Metric; LCSC Part C23179
R9, R12: 100k; R_0603_1608Metric; LCSC Part C25803
U1: TPS70933DBVR; SOT-23-5_L3.0-W1.7-P0.95-LS2.8-BR; LCSC Part C89347
U2: CH340N; SOP-8_L4.9-W3.9-P1.27-LS6.0-BL; LCSC Part C2977777

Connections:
3.3V_MYND: C3.2, H1.11, R2.2, U2.5 (VCC), U2.8 (V3)
5V_MYND: H1.23, Q2.2 (S), R9.2
5V_RPi: H2.2, H2.4, J1.3, J1.4, Q2.3 (D)
/3.3V_AUX: CN1.2, J1.5, J1.6, R1.2, R2.1, R6.2, R10.1
/3.3V_RPi: H2.1, H2.17
/3.3V_STBY: C2.2, R1.1, U1.5 (OUT)
/BT_Ver: H1.24
/CE0: H2.24, J4.7
/CE1: H2.26, J4.8
/DBG_RX: H3.2, J3.4, J8.2, U2.7 (RXD)
/DBG_TX: H3.3, J3.2, J8.3, U2.6 (TXD)
/GPIO_0: H2.27
/GPIO_1: H2.28
/GPIO_4: H2.7
/GPIO_5: H2.29
/GPIO_6: H2.31
/GPIO_12: H2.32
/GPIO_13: H2.33
/GPIO_16: H2.36
/GPIO_17: H2.11
/GPIO_22: H2.15
/GPIO_23: H2.16
/GPIO_24: H2.18
/GPIO_25: H2.22
/GPIO_26: H2.37
/GPIO_27: H2.13
/I2C1_SCL: CN1.4, H2.5, J4.3
/I2C1_SDA: CN1.3, H2.3, J4.1
/I2S_BCLK: H1.6, H2.12, J7.5
/I2S_DIN: H2.38, J7.8
/I2S_DOUT: H2.40, J7.3, R5.1
/I2S_MYND_IN: H1.4, J7.1, R5.2
/I2S_WCLK: H1.8, H2.35, J7.7
/L_3.3V: J5.3, R6.1
/L_GND: J5.2, R7.1
/Line_L_N: H1.15, J2.3
/Line_L_P: H1.13, J2.1
/Line_R_N: H1.19, J2.7
/Line_R_P: H1.17, J2.5
/MCU_PC6: H1.16, J3.7
/MCU_PC7: H1.14, J3.5
/MISO: H2.21, J4.4
/MOSI: H2.19, J4.6
/Mynd_Pwr_EN: H1.18, R8.2
/R_3.3V: J6.3, R10.2
/R_GND: J6.2, R11.2
/SCLK: H2.23, J4.2
/UART0_RX: H1.12, H2.10, J3.6
/UART0_TX: H1.10, H2.8, J3.8
/USB_B_N: H1.20, R4.2
/USB_B_P: H1.22, R3.2
/VSYS: C1.2, H1.9, J1.1, J1.2, U1.1 (IN)
GND: C1.1, C2.1, C3.1, CN1.1, CN1.5, CN1.6, H1.3, H1.5, H1.7, H1.21, H2.6, H2.9, H2.14, H2.20, H2.25, H2.30, H2.34, H2.39, H3.1, J1.7, J1.8, J2.2, J2.4, J2.6, J2.8, J3.1, J3.3, J4.5, J7.2, J7.4, J7.6, J8.1, Q1.2 (S), R7.2, R11.1, R12.1, U1.2 (GND), U2.3 (GND)
unnamed: Q1.3 (D), Q2.1 (G), R9.1
unnamed: Q1.1 (G), R8.1, R12.2
unnamed: R3.1, U2.1 (UD+)
unnamed: R4.1, U2.2 (UD-)

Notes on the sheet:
RPi connector
SMD and THT footprints provided
Miscellaneous Pin Headers
3.3V Supply
Mini Module Footprint
USB-UART converter
Connector to MYND Main PCB
MCU_PB14
5V Switch
UART0_TX/RX from RPi Side, so MCU_TX/RX reversed
Common footprint I2C connector
Names in MYND schematic
When R9 is placed, 3.3V_AUX pcb is supplied always on 3.3V LDO. When R10 is place, power is supplied by MYND only when on. Never connect R9 and R10 simultaneously.
This footprint fits most mini style modules such as the Waveshare Mini series or Seed Studio XIAO series. Since some module have their GND/3.3V connection on left and some on the right side, both options are available to select with R11&R13 populated for power on the left, and R12&R14 for power on 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
Since safety relevant information is transmitted on MYND I2C bus, it is disconnected from MYNDberry I2C bus.
Remove 0Ω jumpers R11&R13 and solder to R12 & R14 for Mini board with power on the right header
By default, RPi I2S out is connected to MYND I2S in. If used with an external DSP or peripheral in between, remove R8.
VSYS - Unregulated battery voltage 6-8.4V 5V_RPI - Switched 5V power supply 3.3V_Aux - Either supplied by MYND when MYND is active or separate always on LDO
A USB-UART converter is inlcluded on the PCB. This can be connected either to MYND Debug Pins on the main pcb or any other device where live debugging/control is useful. USB 5v/GND/d+/d- are also available as testpins.
RPi-5V is off by default and can be enabled by pulling pin PB14 on MCU high.
2x40 Pin connector for any SBC that follows Raspberry Pi pinout

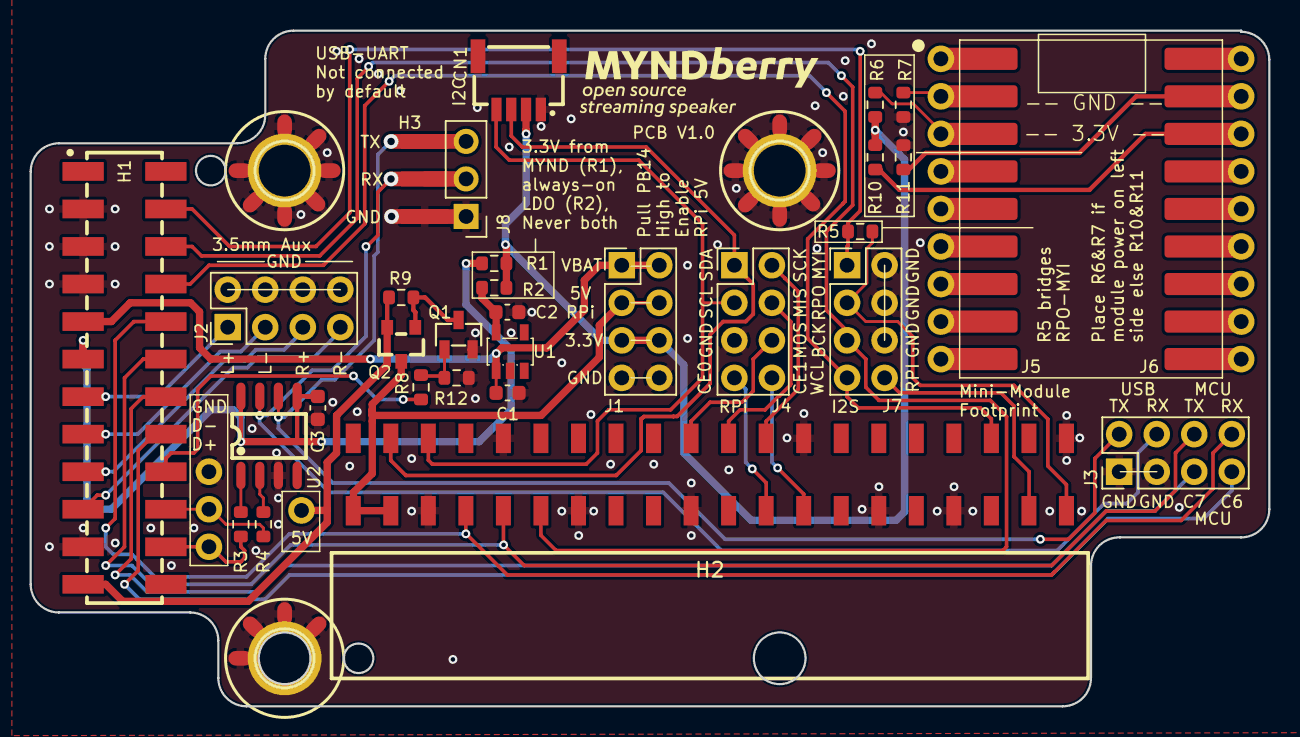
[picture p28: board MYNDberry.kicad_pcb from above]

Board: 2 copper layers, 83.8 x 45.7 mm, 31 parts (0 on the bottom side), 41 nets.

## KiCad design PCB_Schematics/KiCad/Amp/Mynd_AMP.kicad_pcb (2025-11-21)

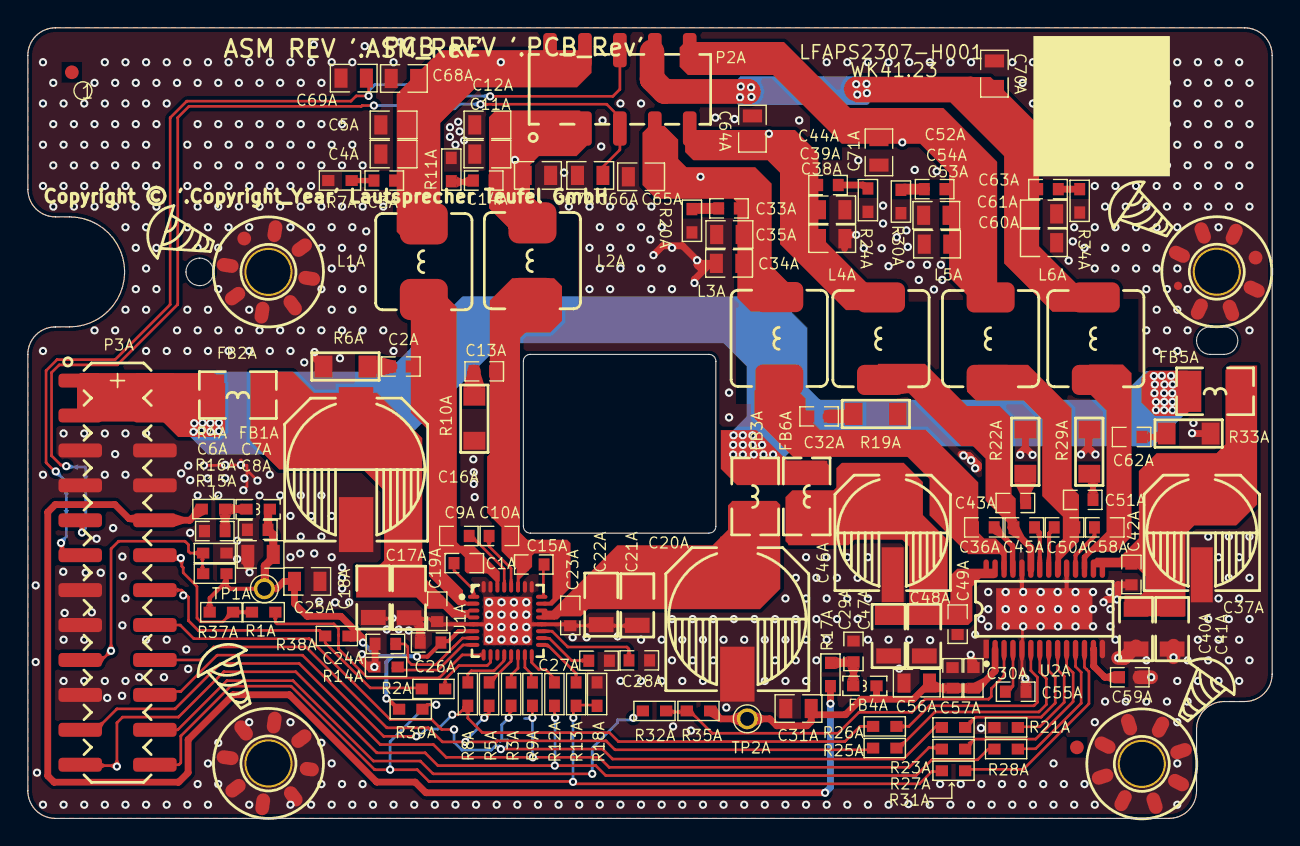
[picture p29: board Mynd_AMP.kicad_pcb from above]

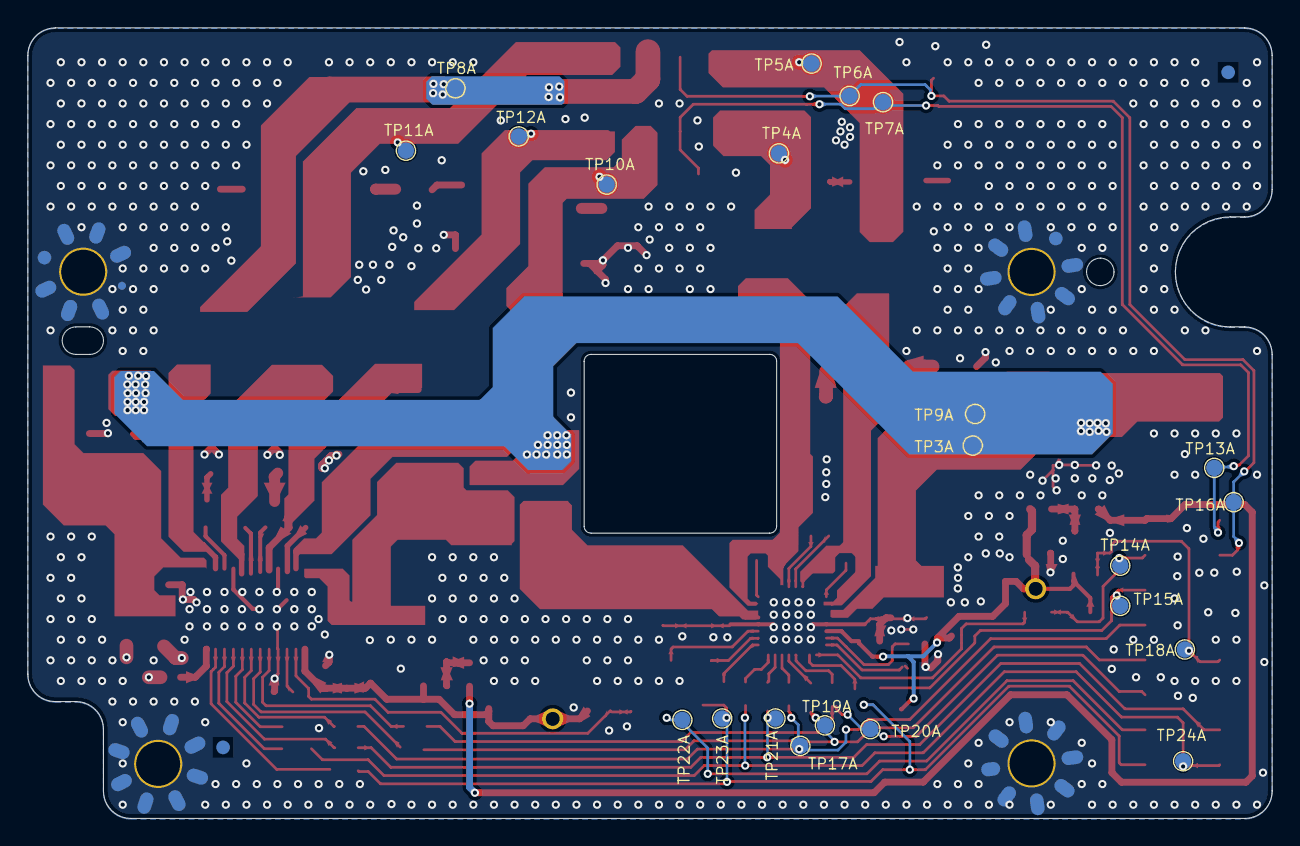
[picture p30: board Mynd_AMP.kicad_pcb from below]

Board: 2 copper layers, 90.5 x 57.5 mm, 159 parts (22 on the bottom side), 77 nets.

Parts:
C1A, C9A, C10A, C15A: 470nF; C0603X100
C2A, C13A, C32A, C43A, C51A, C62A: 330pF; C0603X80
C3A, C14A, C33A, C44A, C52A, C63A: 10nF; C0603X100
C4A, C11A: 680nF; C0805_125
C5A, C12A, C35A, C39A, C54A, C61A, C64A, C65A, C66A, C67A, C68A, C69A, C70A, C71A: 1nF; C0805_125
C6A, C7A, C19A, C23A, C26A, C29A, C30A, C42A, C49A, C57A: 100nF; C0603X105
C8A, C31A: 22uF; C0805_145
C16A, C20A: 470uF; ECAP_SMD_1000X1000
C17A, C18A, C21A, C22A, C40A, C41A, C47A, C48A: 10uF; C1206
C24A, C27A, C28A, C55A, C59A: 1uF; C0603X105
C25A, C56A: 4.7uF; C0805_145
C34A, C38A, C53A, C60A: 330nF; C0805_125
C36A, C45A, C50A, C58A: 220nF; C0603X100
C37A, C46A: 220uF; ECAP_SMD_800X1000
FB1A, FB4A: 600R; L0603
FB2A, FB3A, FB5A, FB6A: 56R; L1612
L1A, L2A: 4.7uH; IND_SMD_YT_SQU_L78XW70XH50
L3A, L4A, L5A, L6A: 10uH; IND_SMD_YT_SQU_L78XW70XH30
MH1A, MH2A, MH3A, MH4A: SCREW_HOLE_D32; SCREW_D32
MK_T1A, MK_T2A: MARK
P2A: 2 x 5P 2.54mm; female_2X5_254
P3A: 2 x 12P 2.54mm; Pin_Header_SMD_2X12_254
R1A, R2A, R13A, R31A, R32A: 10R; R0603
R3A, R5A, R8A, R9A, R12A, R14A, R23A, R25A, R26A, R27A, R28A: 0R; R0603
R4A, R17A: 2.2R; R0603
R6A, R10A, R19A, R22A, R29A, R33A: 10R; R1206
R7A, R11A, R20A, R24A, R30A, R34A: 3.3R; R0603
R15A: 100k; R0603
R16A, R18A, R21A, R37A, R38A: 10k; R0603
R35A: 4.7k; R0603
R39A: NC; R0603
TP1A, TP2A: TP_T_60_40
TP3A, TP4A, TP5A, TP6A, TP7A, TP8A, TP9A, TP10A, TP11A, TP12A, TP13A, TP14A, TP15A, TP16A, TP17A, TP18A, TP19A, TP20A, TP21A, TP22A, TP23A, TP24A: TP12; TP120
Teufel_ASM_Label1A: =Comment/Name; Teufel_ASM_Rev
Teufel_Copyright1A: =Comment/Name; TEUFEL_COPYRIGHT
Teufel_PCB_Label1A: =Comment/Name; Teufel_PCB_Rev
Teufel_PCB_Logo1A: T.3.0.0040-2.1; Teufel_NoLogo
U1A: TAS5825PRHBR; QFN32_500X500X100_50_P350X350
U2A: TAS5805MPWPR; TSSOP28(PWP)

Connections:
3V3_STB: P3A.10, R4A.2, R17A.2
3V3_SW: C7A.1, C8A.1, C25A.1, C26A.1, FB1A.2, R15A.1, R37A.1, R38A.1, R39A.1, TP1A.1, U1A.6
3V3_TW: C30A.1, C31A.1, C56A.1, C57A.1, FB4A.2, R35A.1, TP2A.1, U2A.2
24V: FB2A.1, FB3A.1, FB5A.1, FB6A.2, P3A.1, P3A.2, P3A.3, P3A.4, TP3A.1, TP9A.1
Amp_Ver: P3A.17, R15A.2, R16A.1, TP18A.1
BatVCC: C66A.1, P2A.5, P3A.9, TP7A.1, TP13A.1
C_Open: C69A.1, P2A.6, P3A.11, TP6A.1, TP16A.1
Env_Track: P3A.14, R2A.2, R38A.2, TP15A.1
GND: C4A.2, C5A.2, C6A.2, C7A.2, C8A.2, C11A.2, C12A.2, C16A.2, C17A.2, C18A.2, C19A.2, C20A.2, C21A.2, C22A.2, C23A.2, C24A.1, C25A.2, C26A.2, C27A.1, C28A.1, C29A.2, C30A.2, C31A.2, C34A.2, C35A.2, C37A.2, C38A.2, C39A.2, C40A.2, C41A.2, C42A.2, C46A.2, C47A.2, C48A.2, C49A.2, C53A.2, C54A.2, C55A.1, C56A.2, C57A.2, C59A.1, C60A.2, C61A.2, C64A.2, C65A.2, C66A.2, C67A.2, C68A.2, C69A.2, C70A.2, C71A.2, MH1A.1, MH2A.1, MH3A.1, MH4A.1, P3A.5, P3A.6, P3A.7, P3A.8, P3A.13, P3A.15, P3A.19, R6A.2, R7A.2, R10A.1, R11A.2, R14A.1, R16A.2, R18A.2, R19A.2, R20A.2, R21A.2, R22A.1, R24A.2, R29A.2, R30A.2, R33A.1, R34A.2, U1A.0, U1A.5, U1A.20, U1A.25, U1A.26, U1A.31, U1A.32, U2A.0, U2A.1, U2A.5, U2A.14, U2A.19, U2A.24
I2S_BCLK: P3A.18, R5A.1, R25A.1, TP19A.1
I2S_DATA: P3A.16, R3A.1, R23A.1, TP17A.1
I2S_LRCK: P3A.20, R8A.1, R26A.1, TP20A.1
NetC1A_1: C1A.1, C2A.2, C9A.2, L1A.1, U1A.2, U1A.30
NetC1A_2: C1A.2, U1A.1
NetC2A_1: C2A.1, R6A.1
NetC3A_2: C3A.2, R7A.1
NetC6A_1: C6A.1, FB1A.1, R4A.1
NetC9A_1: C9A.1, U1A.29
NetC10A_1: C10A.1, C13A.1, C15A.2, L2A.1, U1A.23, U1A.27
NetC10A_2: C10A.2, U1A.28
NetC13A_2: C13A.2, R10A.2
NetC14A_1: C14A.1, R11A.1
NetC15A_1: C15A.1, U1A.24
NetC16A_1: C16A.1, C17A.1, C18A.1, C19A.1, FB2A.2, U1A.3, U1A.4
NetC20A_1: C20A.1, C21A.1, C22A.1, C23A.1, FB3A.2, U1A.21, U1A.22
NetC24A_2: C24A.2, U1A.7
NetC27A_2: C27A.2, U1A.18
NetC28A_2: C28A.2, U1A.19
NetC29A_1: C29A.1, FB4A.1, R17A.1
NetC32A_1: C32A.1, R19A.1
NetC32A_2: C32A.2, C36A.1, L3A.1, U2A.26
NetC33A_2: C33A.2, R20A.1
NetC36A_2: C36A.2, U2A.25
NetC37A_1: C37A.1, C40A.1, C41A.1, C42A.1, FB5A.2, U2A.15, U2A.16
NetC43A_1: C43A.1, C45A.2, L4A.1, U2A.23
NetC43A_2: C43A.2, R22A.2
NetC44A_1: C44A.1, R24A.1
NetC45A_1: C45A.1, U2A.22
NetC46A_1: C46A.1, C47A.1, C48A.1, C49A.1, FB6A.1, U2A.27, U2A.28
NetC50A_1: C50A.1, C51A.2, L5A.1, U2A.20
NetC50A_2: C50A.2, U2A.21
NetC51A_1: C51A.1, R29A.1
NetC52A_2: C52A.2, R30A.1
NetC55A_2: C55A.2, U2A.4
NetC58A_1: C58A.1, U2A.18
NetC58A_2: C58A.2, C62A.1, L6A.1, U2A.17
NetC59A_2: C59A.2, U2A.13
NetC62A_2: C62A.2, R33A.2
NetC63A_1: C63A.1, R34A.1
NetR1A_1: R1A.1, U1A.9
NetR2A_1: R2A.1, U1A.10
NetR3A_2: R3A.2, U1A.14
NetR5A_2: R5A.2, U1A.13
NetR8A_2: R8A.2, U1A.12
NetR9A_2: R9A.2, U1A.15
NetR12A_2: R12A.2, U1A.16
NetR13A_1: R13A.1, U1A.17
NetR14A_2: R14A.2, U1A.8
NetR21A_1: R21A.1, U2A.9
NetR23A_2: R23A.2, U2A.8
NetR25A_2: R25A.2, U2A.7
NetR26A_2: R26A.2, U2A.6
NetR27A_2: R27A.2, U2A.10
NetR28A_2: R28A.2, U2A.11
NetR31A_1: R31A.1, U2A.12
NetR32A_1: R32A.1, R35A.2, U2A.3
SCL: P3A.23, R12A.1, R28A.1, TP24A.1
SDA: P3A.21, R9A.1, R27A.1, TP21A.1
SW_N: C11A.1, C12A.1, C14A.2, C67A.1, L2A.2, P2A.1, P2A.3, TP4A.1
SW_P: C3A.1, C4A.1, C5A.1, C68A.1, L1A.2, P2A.2, P2A.4, TP5A.1
TW_L_N: C52A.1, C53A.1, C54A.1, C71A.1, L5A.2, P2A.10, TP11A.1
TW_L_P: C60A.1, C61A.1, C63A.2, C70A.1, L6A.2, P2A.8, TP8A.1
TW_R_N: C38A.1, C39A.1, C44A.2, C64A.1, L4A.2, P2A.9, TP12A.1
TW_R_P: C33A.1, C34A.1, C35A.1, C65A.1, L3A.2, P2A.7, TP10A.1
~Amp_PDN: P3A.24, R13A.2, R18A.1, R31A.2, R39A.2, TP23A.1
~Amp_SwFlt: P3A.12, R1A.2, R37A.2, TP14A.1
~Amp_TwFlt: P3A.22, R32A.2, TP22A.1

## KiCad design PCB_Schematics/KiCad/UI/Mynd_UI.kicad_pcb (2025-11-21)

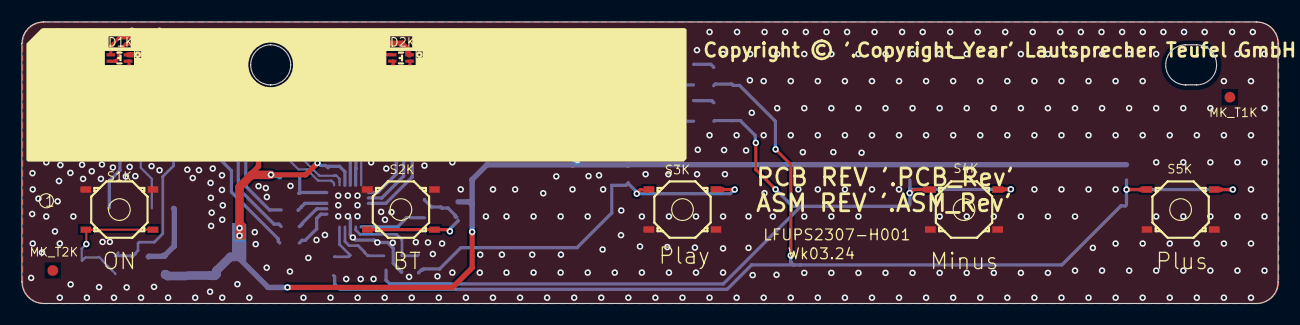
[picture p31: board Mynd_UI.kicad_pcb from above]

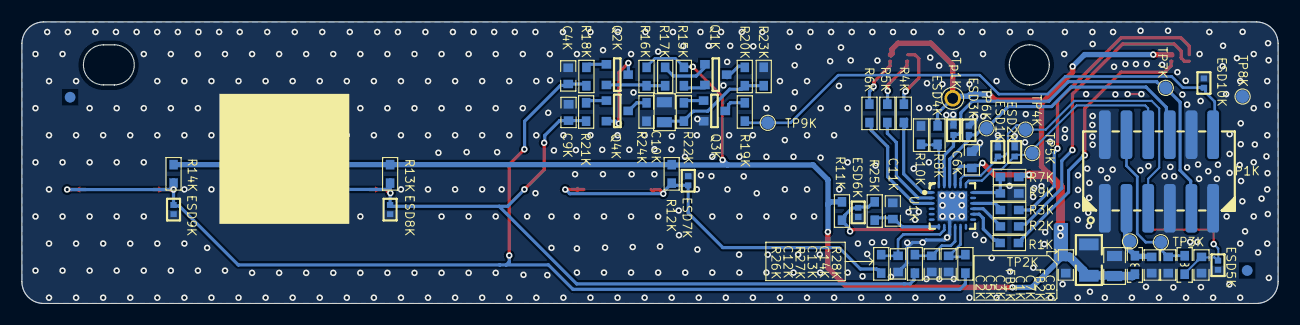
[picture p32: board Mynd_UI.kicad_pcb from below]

Board: 2 copper layers, 116.0 x 26.0 mm, 82 parts (69 on the bottom side), 43 nets.

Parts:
C1K, C2K, C4K, C6K, C9K: 100nF; C0603X100
C3K, C10K: 10uF; C0805_145
C5K: 22uF; C1206
C7K, C8K: 33pF; C0603X80
C11K, C12K, C13K, C14K: NC; C0603X100
D1K, D2K: JH-CRGBB06GTP014; LED_SMD_F_T_160X80X60
ESD1K, ESD2K, ESD3K, ESD4K, ESD6K, ESD7K, ESD8K, ESD9K, ESD10K: CESD0501CU; DFN2_100X60X50_65
ESD5K: BDFN2C121V; DFN2_100X60X50_65
FB1K, FB2K: 600R; L0603
MK_T1K, MK_T2K: MARK
P1K: WB200AL-12; WB200AL_2x6P
Q1K, Q2K, Q4K: CJ3401; SOT23-GSD
Q3K: 2N7002K; SOT23-GSD
R1K, R2K, R5K, R6K: 22R; R0603
R3K, R4K: 75R; R0603
R7K, R8K: 100R; R0603
R9K, R10K, R16K, R22K: 10k; R0603
R11K, R12K, R13K, R14K: 100k; R0603
R15K, R24K: 0R; R0603
R17K: 4.7k; R0603
R18K, R21K: 150k; R0603
R19K: 10R; R0603
R20K: 680k; R0603
R23K: 1M; R0603
R25K, R26K, R27K, R28K: 1k; R0603
S1K, S2K, S3K, S4K, S5K: TC-1316A-H1.5-180GF; TACT_SW_SMD_52X52X15
TP2K, TP3K, TP4K, TP5K, TP6K, TP7K, TP8K, TP9K: TP12; TP120
Teufel_ASM_Label1K: =Comment/Name; Teufel_ASM_Rev
Teufel_Copyright1K: =Comment/Name; TEUFEL_COPYRIGHT
Teufel_PCB_Label1K: =Comment/Name; Teufel_PCB_Rev
Teufel_PCB_Logo1K: T.3.0.0040-3.2; Teufel_NoLogo
Tp1K: TP_T_60_40
U1K: AW9523BTQR; QFN24_400X400X100_50_P270X270

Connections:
3V3_LED: C2K.1, C3K.1, C5K.2, C6K.2, D1K.C, D2K.C, FB1K.1, R7K.2, R8K.2, R11K.1, R12K.1, R13K.1, R14K.1, R15K.1, R16K.2, Tp1K.1, U1K.21
3V3_STB: C1K.1, FB1K.2, P1K.3, TP2K.1
Btn_BT: ESD6K.2, R11K.2, R25K.2, S2K.3, S2K.4
Btn_Minus: C9K.1, ESD8K.2, R13K.2, R21K.1, R27K.2, S4K.3, S4K.4
Btn_On: C8K.1, ESD5K.2, FB2K.2, S1K.3, S1K.4
Btn_Play: ESD7K.2, R12K.2, R26K.2, S3K.3, S3K.4
Btn_Plus: C4K.1, ESD9K.2, R14K.2, R18K.1, R28K.2, S5K.3, S5K.4
GND: C1K.2, C2K.2, C3K.2, C4K.2, C5K.1, C6K.1, C7K.2, C8K.2, C9K.2, C10K.2, C11K.2, C12K.2, C13K.2, C14K.2, ESD1K.1, ESD2K.1, ESD3K.1, ESD4K.1, ESD5K.1, ESD6K.1, ESD7K.1, ESD8K.1, ESD9K.1, ESD10K.1, P1K.1, P1K.2, P1K.7, P1K.10, P1K.11, Q3K.S, R9K.2, R10K.2, R23K.1, R24K.1, S1K.1, S1K.2, S2K.1, S2K.2, S3K.1, S3K.2, S4K.1, S4K.2, S5K.1, S5K.2, TP8K.1, U1K.0, U1K.9
I2C2_SCL: ESD2K.2, P1K.6, TP5K.1, U1K.19
I2C2_SDA: ESD1K.2, P1K.5, TP4K.1, U1K.20
MCU_RST: ESD10K.2, P1K.12, R19K.1, TP9K.1
NetC10K_1: C10K.1, R20K.2, R22K.1, R23K.2
NetC11K_1: C11K.1, R25K.1, U1K.7
NetC12K_1: C12K.1, R26K.1, U1K.8
NetC13K_1: C13K.1, R27K.1, U1K.10
NetC14K_1: C14K.1, R28K.1, U1K.11
NetD1K_B: D1K.B, R1K.1
NetD1K_G: D1K.G, R2K.1
NetD1K_R: D1K.R, R3K.1
NetD2K_B: D2K.B, R6K.1
NetD2K_G: D2K.G, R5K.1
NetD2K_R: D2K.R, R4K.1
NetQ1K_D: Q1K.D, R20K.1
NetQ1K_G: Q1K.G, R17K.2
NetQ1K_S: Q1K.S, R15K.2
NetQ2K_D: Q2K.D, Q4K.S
NetQ2K_G: Q2K.G, R18K.2
NetQ2K_S: Q2K.S, R16K.1, R17K.1
NetQ3K_D: Q3K.D, R19K.2
NetQ3K_G: Q3K.G, R22K.2
NetQ4K_D: Q4K.D, R24K.2
NetQ4K_G: Q4K.G, R21K.2
NetR1K_2: R1K.2, U1K.14
NetR2K_2: R2K.2, U1K.15
NetR3K_2: R3K.2, U1K.16
NetR4K_2: R4K.2, U1K.1
NetR5K_2: R5K.2, U1K.2
NetR6K_2: R6K.2, U1K.3
NetR7K_1: R7K.1, R9K.1, U1K.18
NetR8K_1: R8K.1, R10K.1, U1K.24
\P_Btn: C7K.1, FB2K.1, P1K.4, TP3K.1
\UI_Int: ESD3K.2, P1K.8, TP6K.1, U1K.22
\UI_Rst: ESD4K.2, P1K.9, TP7K.1, U1K.23

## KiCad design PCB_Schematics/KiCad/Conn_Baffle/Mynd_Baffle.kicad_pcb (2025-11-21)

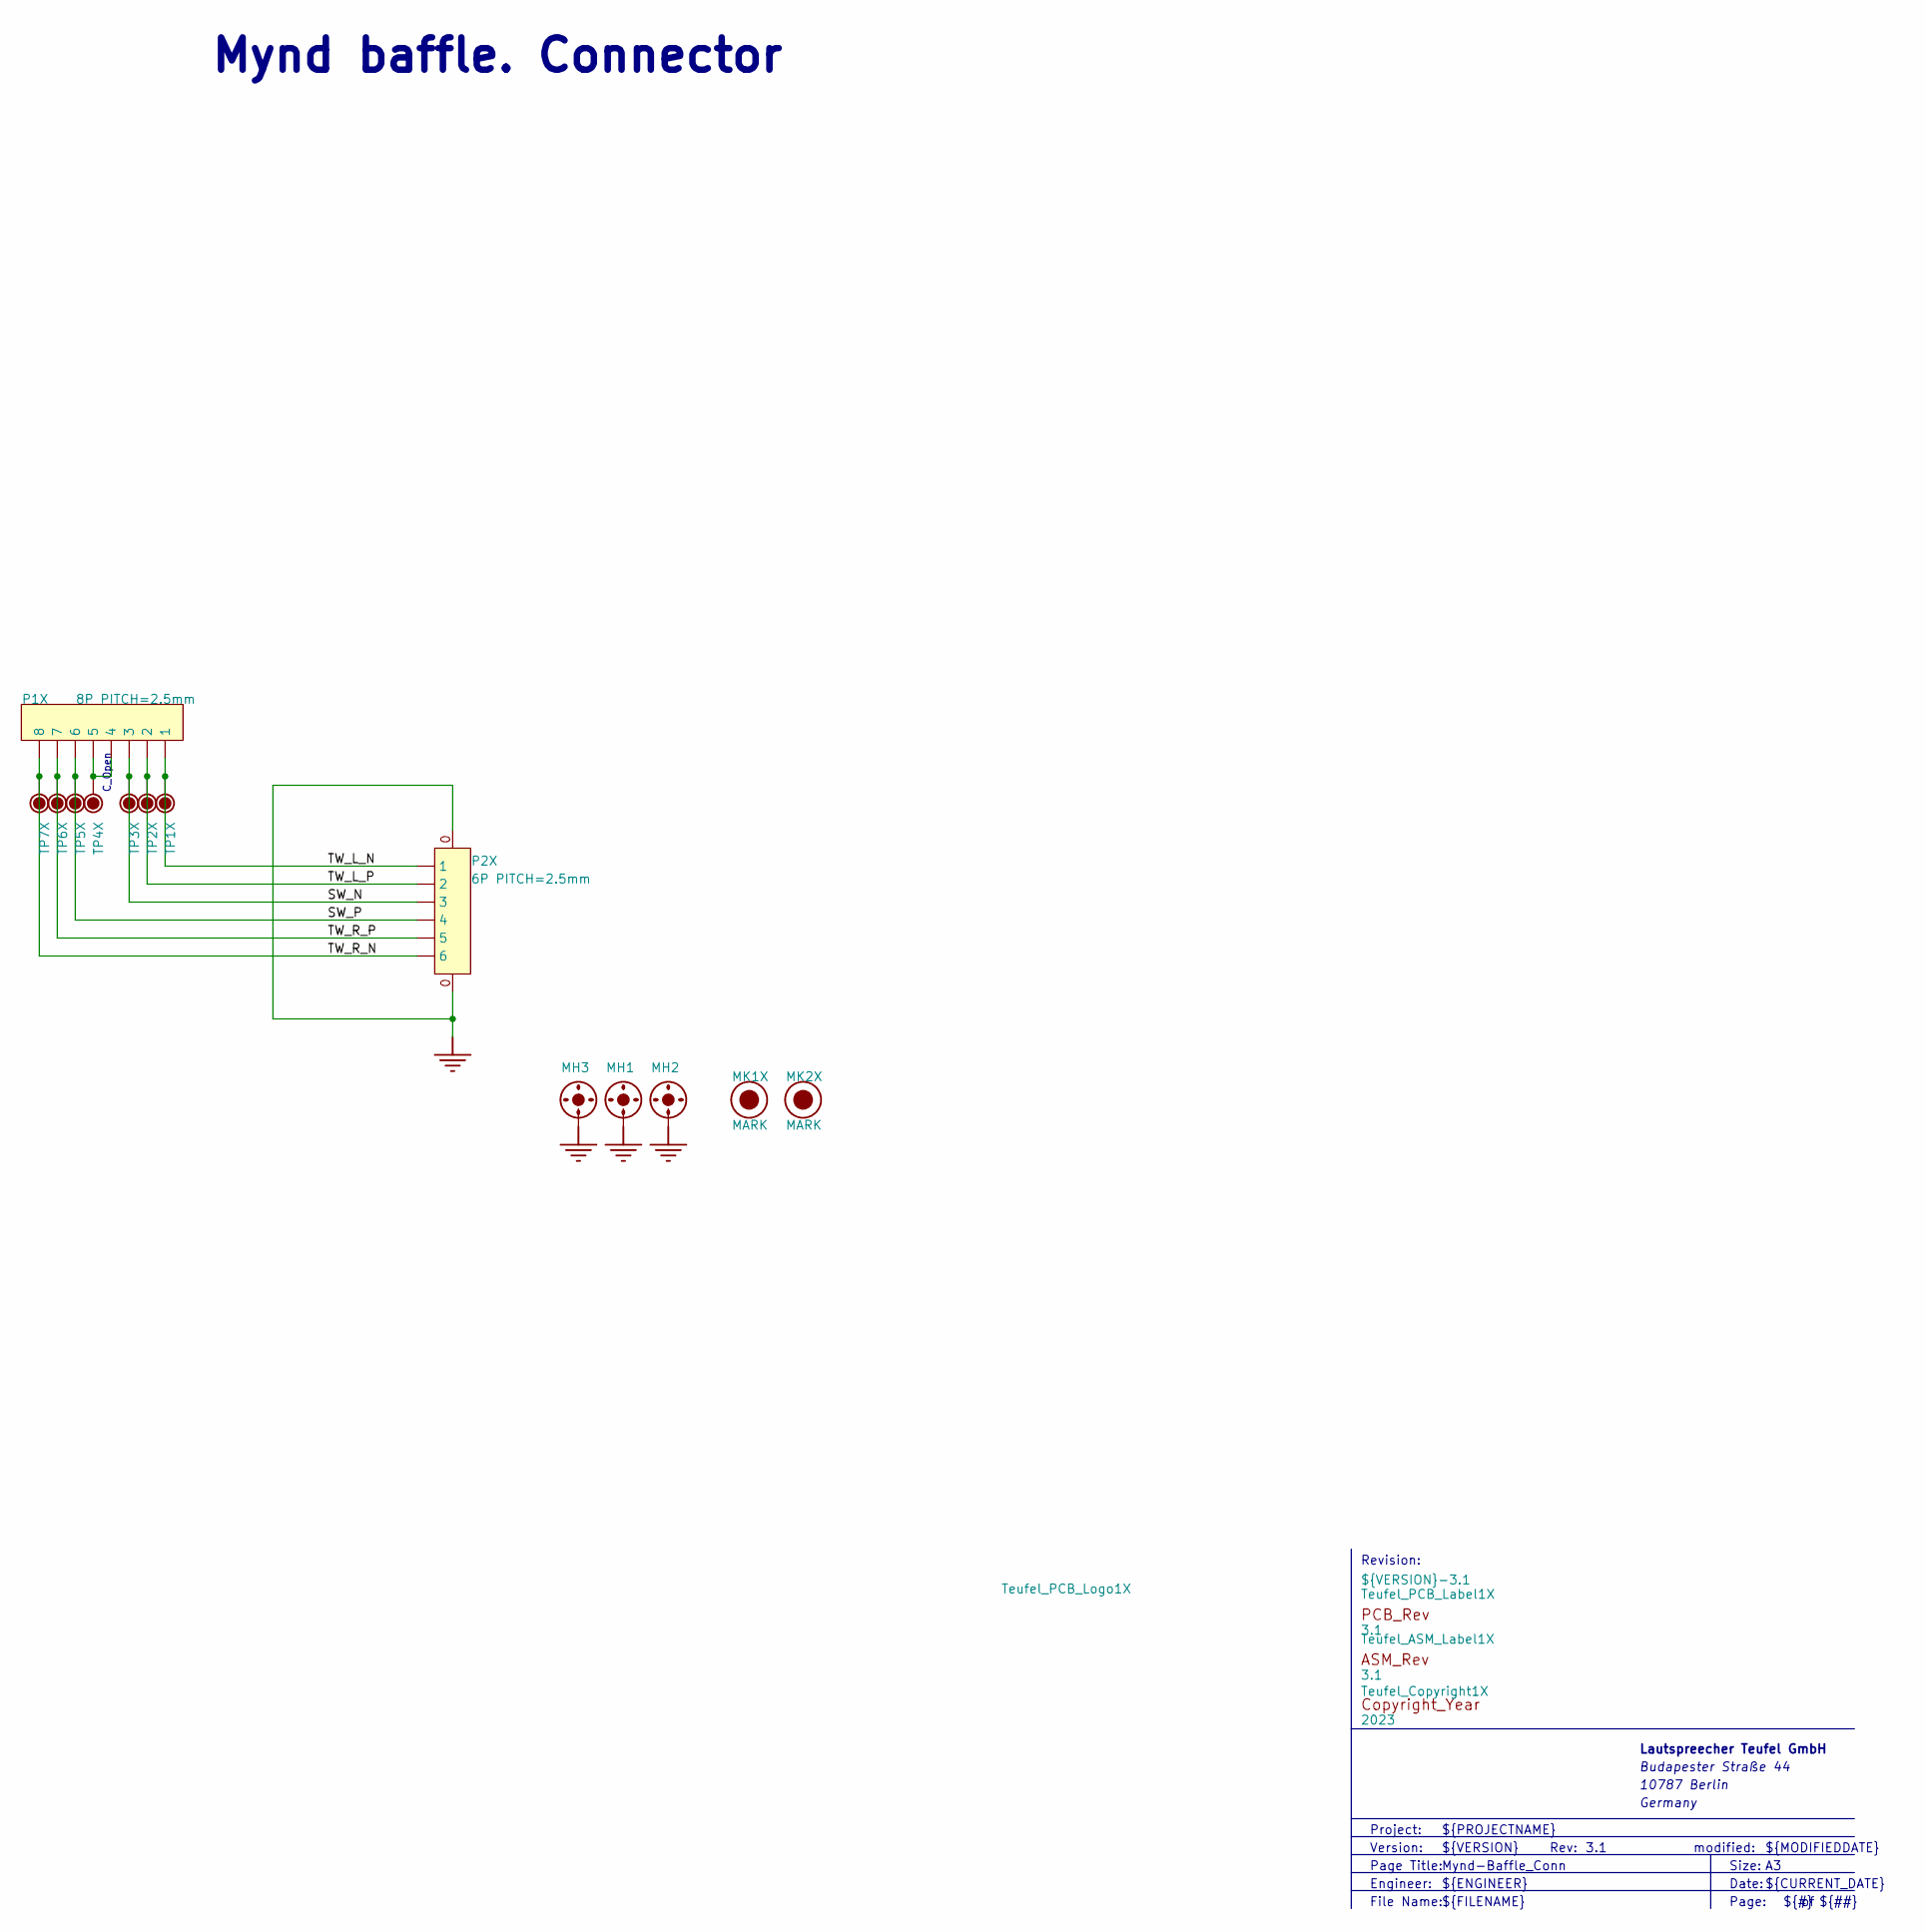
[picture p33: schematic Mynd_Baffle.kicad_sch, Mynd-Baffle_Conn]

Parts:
MH1, MH3: SCREW_HOLE_D35; SCREW_D35
MH2: HOLD_D35
MK1X, MK2X: MARK
P1X: 8P PITCH=2.5mm; TSB1_05282; PART_NUMBER 8P PITCH=2.5mm
P2X: 6P PITCH=2.5mm; CON_250_SMD_V_6P; PART_NUMBER 6P PITCH=2.5mm
TP1X, TP2X, TP3X, TP4X, TP5X, TP6X, TP7X: TP12; TP120
Teufel_ASM_Label1X: 3.1; Teufel_ASM_Rev
Teufel_Copyright1X: 2023; TEUFEL_COPYRIGHT
Teufel_PCB_Label1X: 3.1; Teufel_PCB_Rev
Teufel_PCB_Logo1X: ${VERSION}-${REVISION}; Teufel_NoLogo

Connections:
GND: MH1.1, MH2.1, MH3.1, P2X.0
NetP1X_4: P1X.4, P1X.5, TP4X.1
SW_N: P1X.3, P2X.3, TP3X.1
SW_P: P1X.6, P2X.4, TP5X.1
TW_L_N: P1X.1, P2X.1, TP1X.1
TW_L_P: P1X.2, P2X.2, TP2X.1
TW_R_N: P1X.8, P2X.6, TP7X.1
TW_R_P: P1X.7, P2X.5, TP6X.1

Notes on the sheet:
modified:
C_Open
${CURRENT_DATE}
Mynd baffle. Connector
Version:
Date:
File Name:
Page Title:
${FILENAME}
${MODIFIEDDATE}
Lautspreecher Teufel GmbH
Engineer:
${TITLE}
10787 Berlin
Budapester Straße 44
${##}
${ENGINEER}
Project:
Rev:
${PROJECTNAME}
${REVISION}
${VERSION}
Revision:
${#}
Size:
Page:
Germany

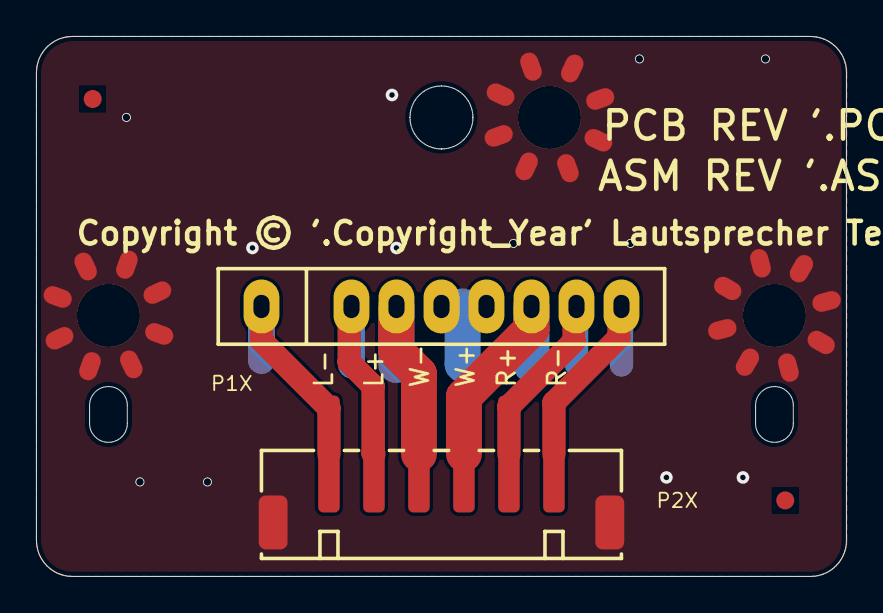
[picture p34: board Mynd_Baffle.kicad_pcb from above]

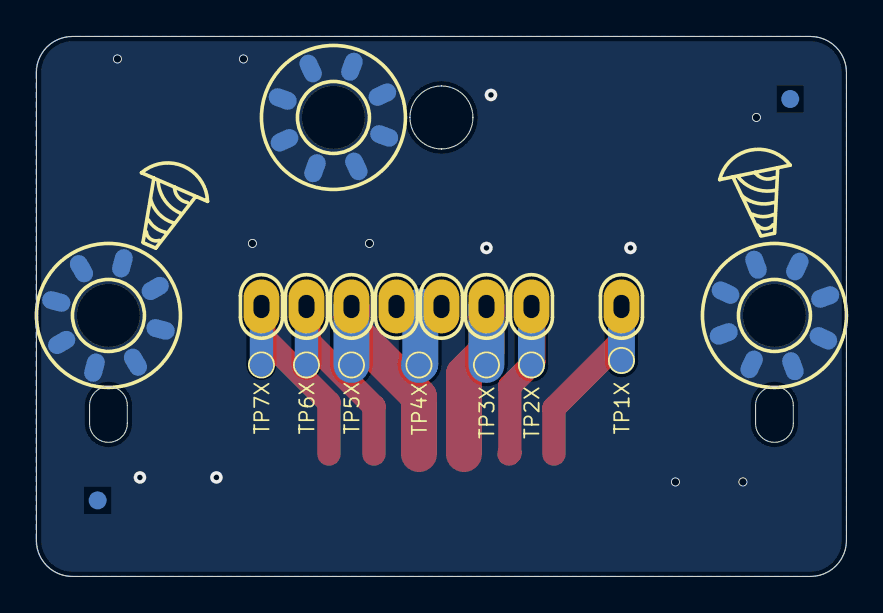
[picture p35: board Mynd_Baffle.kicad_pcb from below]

Board: 2 copper layers, 45.0 x 30.0 mm, 18 parts (10 on the bottom side), 8 nets.

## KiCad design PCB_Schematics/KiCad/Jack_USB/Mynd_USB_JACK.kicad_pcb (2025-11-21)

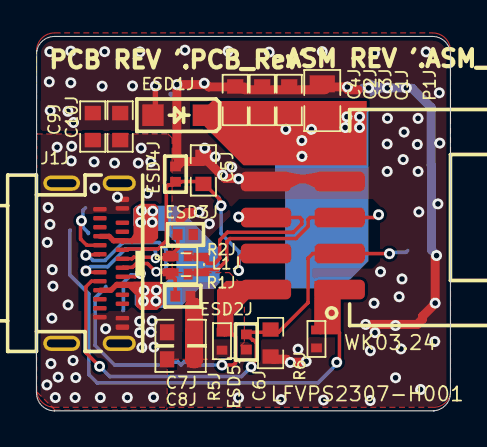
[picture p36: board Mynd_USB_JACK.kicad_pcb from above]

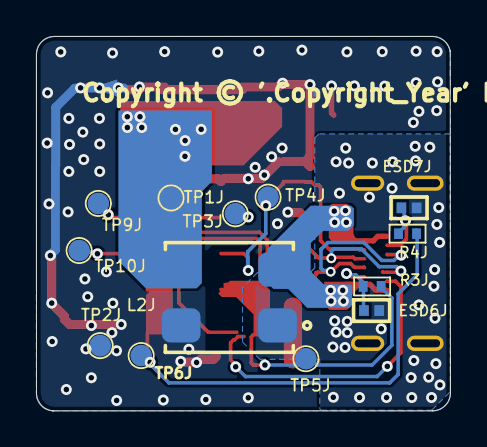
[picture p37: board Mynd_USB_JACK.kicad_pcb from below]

Board: 2 copper layers, 23.0 x 20.8 mm, 39 parts (14 on the bottom side), 14 nets.

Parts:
C1J: 2.2uF; C0805_145
C2J, C8J, C10J: 100nF; C0603X100
C3J, C4J: 10nF; C0603X100
C5J, C6J: 470pF; C0603X80
C7J, C9J: 1nF; C0603X100
ESD1J: SMF26AL; SOD-123FL
ESD2J, ESD3J, ESD4J, ESD5J, ESD6J, ESD7J: CESD0501CU; DFN2_100X60X50_65
J1J: NG-HC-0412; USB_TYPE_C_HC_0768
L1J: 90R; CET2012D
L2J: 700R; DU_IND_SMD_SCM7060
P1J: WB200AW-10; WB200AW_2x5P
R1J, R2J, R3J, R4J: 0R; R0402
R5J, R6J: NC; R0402
TP1J, TP2J, TP3J, TP4J, TP5J, TP6J, TP9J, TP10J: TP12; TP120
Teufel_ASM_Label1J: 3.2; Teufel_ASM_Rev
Teufel_Copyright1K: 2023; TEUFEL_COPYRIGHT
Teufel_PCB_Label1J: 3.2; Teufel_PCB_Rev
Teufel_PCB_Logo1K: T.3.0.0040-3.2; Teufel_NoLogo

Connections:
D2_1_N: ESD2J.2, J1J.A7, J1J.B7, L1J.2, R1J.1
D2_1_P: ESD3J.2, J1J.A6, J1J.B6, L1J.1, R2J.1
GND: C1J.2, C2J.2, C3J.2, C4J.2, C5J.2, C6J.2, C7J.2, C8J.2, C9J.2, C10J.2, ESD1J.A, ESD2J.1, ESD3J.1, ESD4J.2, ESD5J.2, L2J.4, P1J.7, P1J.8, R5J.1, R6J.1, TP2J.1
NetC7J_1: C7J.1, C8J.1, C9J.1, C10J.1, ESD6J.1, ESD7J.1, J1J.A1, J1J.A12, J1J.B1, J1J.B12, J1J.G1, J1J.G2, J1J.G3, J1J.G4, L2J.1
NetESD6J_2: ESD6J.2, J1J.A8, R3J.1
NetESD7J_2: ESD7J.2, J1J.B8, R4J.1
NetJ1J_A4: J1J.A4, J1J.A9, J1J.B4, J1J.B9, L2J.2
USB-CC1: C5J.1, ESD4J.1, J1J.A5, P1J.4, TP4J.1
USB-CC2: C6J.1, ESD5J.1, J1J.B5, P1J.3, TP10J.1
USB_J_N: L1J.3, P1J.5, R1J.2, TP9J.1
USB_J_P: L1J.4, P1J.6, R2J.2, TP3J.1
USB_SBU1: P1J.2, R3J.2, R5J.2, TP5J.1
USB_SBU2: P1J.1, R4J.2, R6J.2, TP6J.1
VBUS_C: C1J.1, C2J.1, C3J.1, C4J.1, ESD1J.K, L2J.3, P1J.9, P1J.10, TP1J.1

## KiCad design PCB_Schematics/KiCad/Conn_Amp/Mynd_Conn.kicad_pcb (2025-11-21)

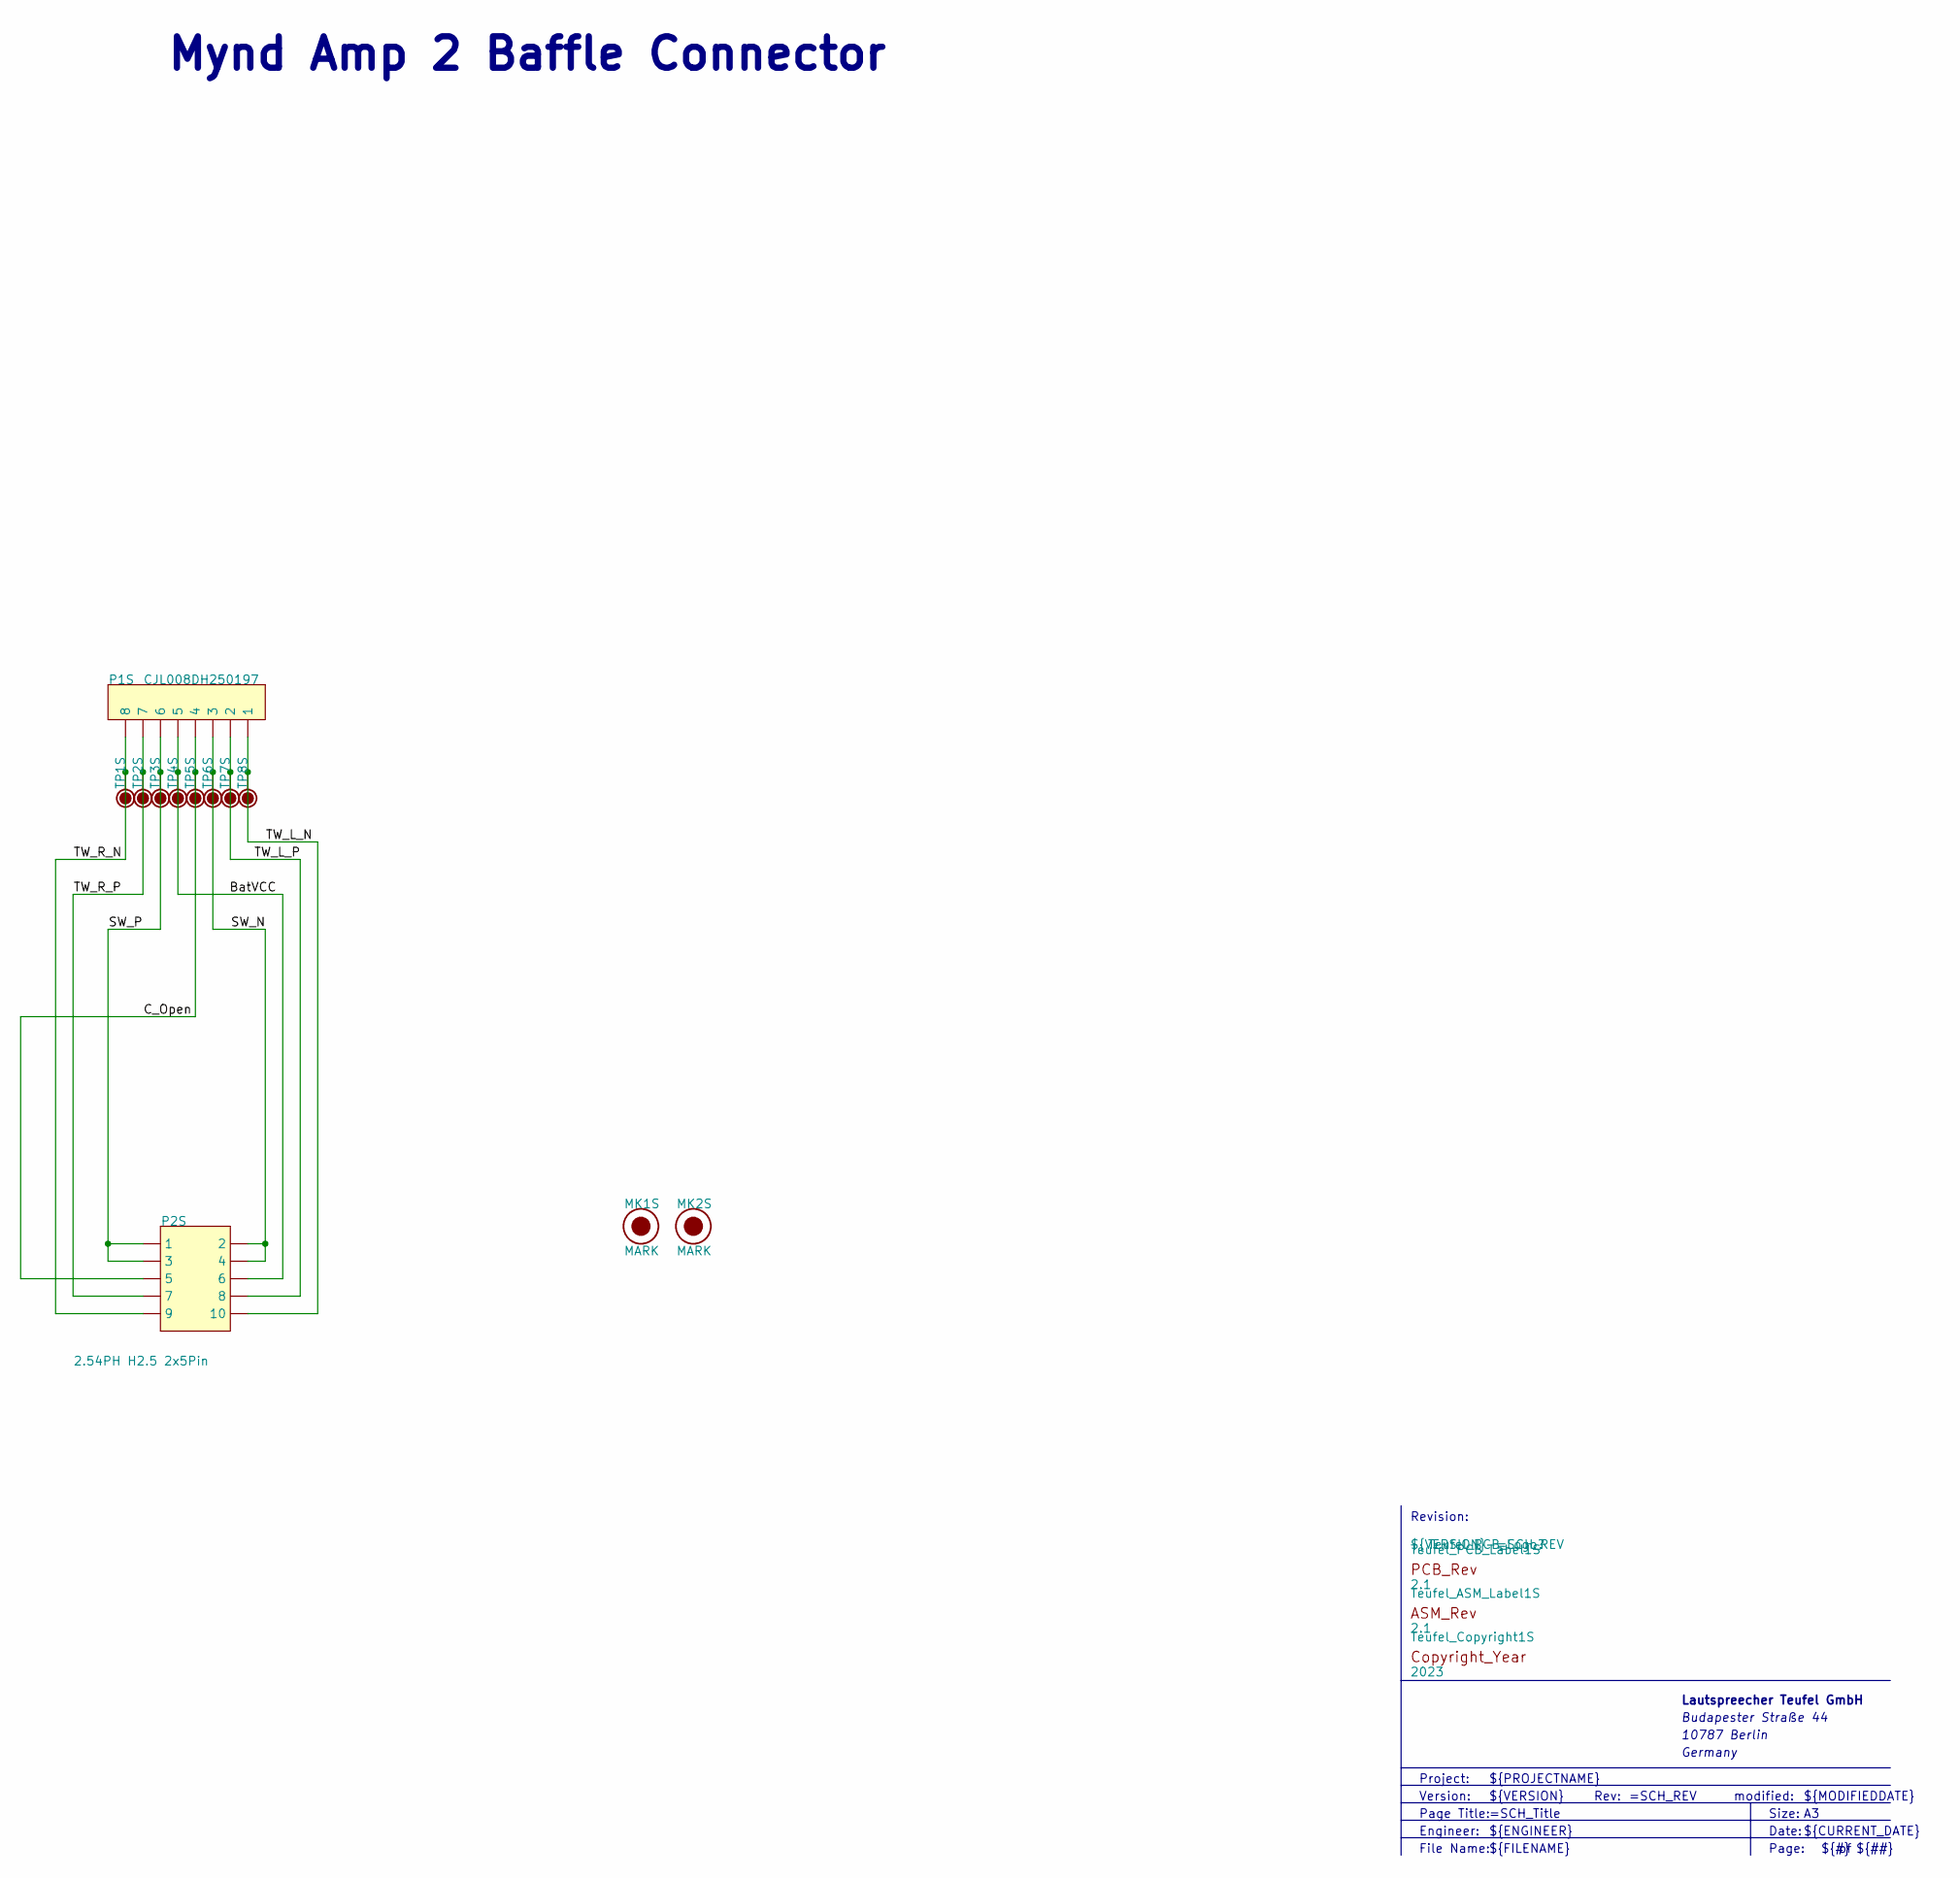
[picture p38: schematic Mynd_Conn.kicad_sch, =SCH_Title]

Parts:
MK1S, MK2S: MARK
P1S: CJL008DH250197; PART_NUMBER CJL008DH250197
P2S: 2.54PH H2.5 2x5Pin; Pin_Header_SMD_Side_2X5_254; PART_NUMBER 2.54PH H2.5 2x5Pin
TP1S, TP2S, TP3S, TP4S, TP5S, TP6S, TP7S, TP8S: TP12; TP120
Teufel_ASM_Label1S: 2.1; Teufel_ASM_Rev
Teufel_Copyright1S: 2023; Teufel_Copyright
Teufel_PCB_Label1S: 2.1; Teufel_PCB_Rev

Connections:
BatVCC: P1S.5, P2S.6, TP4S.1
C_Open: P1S.4, P2S.5, TP5S.1
SW_N: P1S.3, P2S.2, P2S.4, TP6S.1
SW_P: P1S.6, P2S.1, P2S.3, TP3S.1
TW_L_N: P1S.1, P2S.10, TP8S.1
TW_L_P: P1S.2, P2S.8, TP7S.1
TW_R_N: P1S.8, P2S.9, TP1S.1
TW_R_P: P1S.7, P2S.7, TP2S.1

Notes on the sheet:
Mynd Amp 2 Baffle Connector
${FILENAME}
Date:
Version:
Germany
Size:
Page Title:
${PROJECTNAME}
Lautspreecher Teufel GmbH
modified:
Budapester Straße 44
${REVISION}
${MODIFIEDDATE}
Revision:
Project:
${#}
Rev:
${ENGINEER}
File Name:
${CURRENT_DATE}
${VERSION}
Page:
${##}
Engineer:
${TITLE}
10787 Berlin



Board: 2 copper layers, 27.0 x 54.0 mm, 16 parts (8 on the bottom side), 8 nets.

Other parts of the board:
Teufel_PCB_Logo?: T.3.0.0040-2.1; Teufel_NoLogo

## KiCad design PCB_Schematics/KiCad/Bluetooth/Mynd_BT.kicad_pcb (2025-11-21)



Board: 4 copper layers, 55.0 x 41.0 mm, 136 parts (66 on the bottom side), 79 nets.

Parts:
C1W, C2W: 0.5pF; C0402
C3W, C4W, C5W, C7W, C11W, C12W, C15W, C17W, C21W, C23W, C24W, C26W, C28W, C30W, C34W, C35W: 10uF; C0805_145
C6W, C8W, C10W, C14W, C16W, C18W, C19W, C20W, C22W, C25W, C27W, C29W, C31W: 100nF; C0603X100
C32W: 100pF; C0603X80
C33W: 1nF; C0603X100
D1W: 1N4148; SOD-323
FB1W, FB2W, FB3W: 0R; R0603
FB4W, FB5W: 600R; L0603
J1W: 9181-000030; I-PEX MHF
L1W: 0R; R0402
L2W: 90R; COM_CHOKE_SMD_ICMF062P
MH1W, MH2W, MH3W, MH4W: SCREW_HOLE; SCREW_D32
MK1W, MK2W: MARK
P1W: Header 3P PITCH=2.54mm SMT; Pin_Header_SMD_S_T_254_3P
P2W: Connector 2 x 12P 2.54mm SMT; Pin_Header_SMD_2X12_254
Q3W: CJ3401; SOT23-GSD
Q4W: 2N7002K; SOT23-GSD
R1W, R3W, R4W, R27W, R28W, R29W, R30W, R31W, R32W, R34W, R35W, R36W, R37W: 33R; R0603
R2W, R11W, R13W, R15W, R25W, R26W, R33W: 10k; R0603
R5W, R6W, R9W, R16W, R21W: 0R; R0603
R7W, R12W: 3.3k; R0603
R8W, R14W: 6.8k; R0603
R10W: 100k; R0603
R18W: 33k; R0603
R19W, R24W, R41W: 47k; R0603
R20W, R23W, R39W: 1k; R0603
R22W: 2.2R; R0805
R38W: 1M; R0603
R40W: 560k; R0603
R42W: 680k; R0603
R43W: 150k; R0603
R44W: 20k; R0603
R45W: 100k; R0402
TP1W, TP2W, TP3W, TP4W, TP5W, TP6W, TP7W, TP9W, TP10W, TP12W, TP14W, TP15W, TP16W, TP17W, TP18W, TP19W, TP20W, TP21W, TP22W, TP23W, TP25W, TP26W, TP27W, TP28W, TP29W, TP30W, TP31W, TP32W, TP33W, TP34W: TP12; TP120
TP11W, TP13W: TP06; TP060
Teufel_ASM_Label1W: =Comment/Name; Teufel_ASM_Rev
Teufel_Copyright1W: =Comment/Name; TEUFEL_COPYRIGHT
Teufel_PCB_Label1W: =Comment/Name; Teufel_PCB_Rev
Teufel_PCB_Logo1W: T.3.0.0040-3.1; Teufel_NoLogo
U1W: WB-2835P; BT_59P_L260XW150XH26_P105
U2W: RCI025064-B000; SO_8_200
U3W: SGM2036-ADJYN5G/TR; SOT23-5
U4W: APS6404L-3SQN; SO-8

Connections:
3V3_STB: P2W.11, R10W.1, TP28W.1
5V_CCPD: C24W.1, C25W.2, P2W.23, R22W.2, TP34W.1, U3W.1
AGND: R21W.2, U1W.30, U1W.43
BT_2_BCLK: FB1W.1, P2W.6, TP1W.1, TP16W.1
BT_2_LRCK: FB2W.1, P2W.8, TP3W.1, TP17W.1
BT_2_SDAT: FB3W.1, P2W.4, TP4W.1, TP15W.1
BT_AVCC: C16W.1, C17W.2, U1W.44
BT_Ctrl_Pwr: P2W.14, R20W.2, R23W.1, TP20W.1
BT_Ctrl_Vreg: P2W.18, TP12W.1
BT_RTCVDD: C7W.1, C8W.1, R38W.1, U1W.54
BT_SCL: P2W.2, R5W.1, R15W.2, TP10W.1, TP14W.1
BT_SDA: P2W.1, R6W.1, R11W.2, TP9W.1, TP25W.1
BT_SVCC: C14W.1, C15W.2, R18W.1, U1W.45
BT_VBAT: C10W.2, C11W.2, C28W.1, C29W.2, FB4W.2, TP11W.1, U1W.51
BT_VBUS: C22W.1, C23W.1, C30W.2, C31W.2, FB5W.2, TP13W.1, U1W.50
BT_VCC: C4W.2, C6W.2, C12W.2, C18W.2, C20W.1, C21W.1, R11W.1, R15W.1, R25W.1, R26W.1, R33W.1, U1W.49, U2W.3, U2W.7, U2W.8, U4W.8
BT_Ver: P2W.24, R10W.2, R13W.1, TP7W.1
BUD_N: L2W.4, U1W.28
BUD_P: L2W.3, U1W.27
FLASH_CS: R33W.2, R34W.2, U2W.1
FLASH_MISO: R36W.2, U2W.2
FLASH_MOSI: R37W.2, U2W.5
FLASH_SCLK: R35W.2, U2W.6
GND: C1W.2, C2W.2, C4W.1, C6W.1, C7W.2, C8W.2, C10W.1, C11W.1, C12W.1, C14W.2, C15W.1, C16W.2, C17W.1, C18W.1, C19W.2, C20W.2, C21W.2, C22W.2, C23W.2, C24W.2, C25W.1, C26W.2, C27W.1, C28W.2, C29W.1, C30W.1, C31W.1, C32W.1, C33W.1, J1W.2, MH1W.1, MH2W.1, MH3W.1, MH4W.1, P1W.3, P2W.3, P2W.5, P2W.7, P2W.21, Q4W.S, R13W.2, R19W.2, R21W.1, R24W.2, R40W.2, R41W.2, R44W.1, TP26W.1, TP33W.1, U1W.2, U1W.29, U1W.52, U2W.4, U3W.2, U4W.4
GPIO0: R5W.2, U1W.59
GPIO1: R6W.2, U1W.57
GPIO2/UART_RX: P1W.1, U1W.58
GPIO3/UART_TX: P1W.2, U1W.56
GPIO8: R27W.1, U1W.12
GPIO9: R28W.1, R35W.1, U1W.13
GPIO10: R30W.1, R36W.1, U1W.11
GPIO11: R29W.1, R37W.1, U1W.9
GPIO13: R32W.1, U1W.14
GPIO14: R31W.1, U1W.15
GPIO16: R34W.1, U1W.8
Line_L_N: P2W.15, R9W.2, TP30W.1
Line_L_P: P2W.13, R7W.2, TP29W.1
Line_R_N: P2W.19, R16W.2, TP32W.1
Line_R_P: P2W.17, R12W.2, TP31W.1
MCU_RX: P2W.10, TP5W.1, TP18W.1, U1W.20
MCU_TX: P2W.12, TP6W.1, TP19W.1, U1W.17
NetC1W_1: C1W.1, J1W.1, L1W.1
NetC2W_1: C2W.1, L1W.2, U1W.1
NetC3W_1: C3W.1, U1W.39
NetC3W_2: C3W.2, R7W.1, R14W.2
NetC5W_1: C5W.1, U1W.41
NetC5W_2: C5W.2, R8W.2, R12W.1
NetC19W_1: C19W.1, Q3W.S, R22W.1, R45W.1
NetC26W_1: C26W.1, C27W.2, FB4W.1, R42W.1, U3W.5
NetC32W_2: C32W.2, R39W.2, U1W.53
NetC33W_2: C33W.2, R18W.2, U1W.46
NetC34W_1: C34W.1, U1W.40
NetC34W_2: C34W.2, R9W.1, R14W.1
NetC35W_1: C35W.1, U1W.42
NetC35W_2: C35W.2, R8W.1, R16W.1
NetD1W_A: D1W.A, R2W.1, R41W.1
NetFB1W_2: FB1W.2, R1W.2
NetFB2W_2: FB2W.2, R3W.2
NetFB3W_2: FB3W.2, R4W.2
NetFB5W_1: FB5W.1, Q3W.D
NetQ3W_G: Q3W.G, Q4W.D, R45W.2
NetQ4W_G: Q4W.G, R23W.2, R24W.1
NetR1W_1: R1W.1, U1W.6
NetR3W_1: R3W.1, U1W.5
NetR4W_1: R4W.1, U1W.4
NetR19W_1: R19W.1, R20W.1, U3W.3
NetR42W_2: R42W.2, R43W.2, U3W.4
NetR43W_1: R43W.1, R44W.2
ON/OFF: D1W.K, R38W.2, R39W.1, R40W.1
PSRAM_CE: R27W.2, U4W.1
PSRAM_SCLK: R28W.2, U4W.6
PSRAM_SIO0: R29W.2, U4W.5
PSRAM_SIO1: R30W.2, U4W.2
PSRAM_SIO2: R26W.2, R31W.2, U4W.3
PSRAM_SIO3: R25W.2, R32W.2, U4W.7
USB_B_N: L2W.2, P2W.20, TP22W.1
USB_B_P: L2W.1, P2W.22, TP23W.1
VSys: P2W.9, TP27W.1
\BT_RST: P2W.16, R2W.2, TP2W.1, TP21W.1

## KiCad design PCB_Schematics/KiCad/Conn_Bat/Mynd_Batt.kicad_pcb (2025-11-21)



Board: 2 copper layers, 41.0 x 21.0 mm, 15 parts (7 on the bottom side), 4 nets.

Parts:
MH1T, MH2T: SCREW_HOLE; SCREW_D30
MK1T, MK2T: MARK
P1T: 8P PITCH=2.5mm; TSB1_05282
P2T: WT250MW-084R-0W; CON_250_SMD_H_8P
TP1T, TP2T, TP3T, TP4T, TP5T, TP6T: TP12; TP120
Teufel_ASM_Label1T: 3.1; Teufel_ASM_Rev
Teufel_Copyright1T: 2023; TEUFEL_COPYRIGHT
Teufel_PCB_Logo1T: Teufel_NoLogo

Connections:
Bat+: P1T.1, P1T.2, P1T.3, P2T.6, P2T.7, P2T.8, TP5T.1, TP6T.1
Bat-: MH1T.1, MH2T.1, P1T.6, P1T.7, P1T.8, P2T.0, P2T.1, P2T.2, P2T.3, TP1T.1, TP2T.1
C_Open: P1T.5, P2T.4, TP3T.1
NTC: P1T.4, P2T.5, TP4T.1

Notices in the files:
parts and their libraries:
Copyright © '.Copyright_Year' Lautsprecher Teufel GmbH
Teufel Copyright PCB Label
